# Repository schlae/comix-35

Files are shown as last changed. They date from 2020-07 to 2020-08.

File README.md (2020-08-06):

# COMIX-35 Home Computer
The COMIX-35 is an open-source clone of the 1980s COMX-35 8-bit home computer.
It uses the RCA 1802 microprocessor which is strange and slow but holds the
distinction of being the first CMOS microprocessor. The "35" is because the
original computer has 32K of main memory + 3K of video RAM.

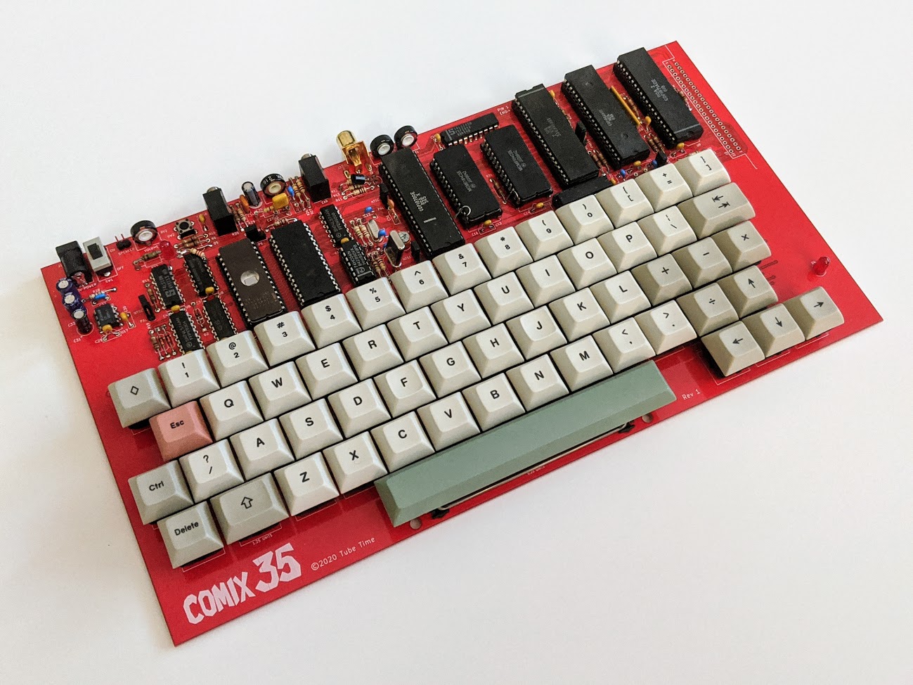
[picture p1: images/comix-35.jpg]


There are a number of differences between the COMIX-35 and the original:

* Single +5V power supply
* Uses SRAM; no stolen cycles for DRAM refresh
* Configurable PAL or NTSC by changing three jumpers and swapping a crystal
* Additional CPU crystal for a new turbo mode
* Mechanical key switches for your typing comfort
* Cassette input data light indicates incoming information

## Design files

Here are the design files. The BOM includes Mouser part numbers for everything
except the CDP1802, CDP1869, CDP1870, CDP1871, the trimmer capacitor (optional),
and the expansion slot header (also optional). I recommend you purchase IC
sockets for the four CDP parts, as well as for the ROM chip U15.

[Schematic](https://github.com/schlae/comix-35/blob/master/COMIX-35.pdf)

[Bill of Materials](https://github.com/schlae/comix-35/blob/master/COMIX-35.csv)

[Fab Files](https://github.com/schlae/comix-35/blob/master/fab/COMIX-35.zip)

The board is rather large, at 12 x 6.5 inches (304.8 x 165.1 mm), but it does
include the keyboard. It is a 2-layer design so it should be relatively cheap
to manufacture. A word of advice: pick out your keycap set first, then choose
the PCB color to match it.

The keyboard keyswitches are easily substituted for lower-cost ones from other
vendors. I recommend you purchase DSA-profile keycaps since some of the keys
are located in rows that are not typical. I ended up buying the [YMDK 125 DSA Dye Sub 9009 Retro PBT Full Keyset for MX](https://www.amazon.com/gp/product/B083L6FVPN/). You can choose whatever you want, but make sure there is a 1 unit
control key and a 1.25 unit shift key. The enter key needs to be 1.5 unit, so
I just used the tab key for that instead. If you have any doubt, check the PCB
layout which has the key cap unit sizes marked below each key.

I have not included part numbers for the 0.1" headers which usually come as a
long strip that you break into the appropriately-sized sections.

Most other components may be safely substituted. U4 is a little tricky. It
should be a 74HCU04 in order for the oscillators to operate, but in a pinch,
a 74HC04 will also work. A 74LS04 or a part from another logic family will
not work.

## Assembly notes
Since the standard COMX-35 ROM configures the CDP1869 to use extra-tall
characters, you need to tie CDP1869 pin 25 to CMA3. Do this by soldering a
jumper wire from pin 1-2 on JP6. If you wish to write your own code to deal
with short characters and more text pages, then install a 0.1" header and
jumper instead.

The default configuration for PAL is as follows:

| Location | PAL | NTSC |
| --- | --- | --- |
| JP1 | 2-3 | 1-2 |
| JP2 | 2-3 | 1-2 |
| JP3 | 2-3 | 1-2 |
| Y1 | 17.734 MHz | 14.318MHz |

The trimmer capacitor, C12, is optional. It allows you to adjust the color
image for best clarity. If you don't use it, then just stuff C13 with a 22pF
capacitor.

You can also configure your COMIX-35 for turbo mode which allows the CPU to
run at much higher frequencies than the original computer, limited only by
the maximum frequency of your particular CDP1802. Check the datasheet for the
variation you have, or experiment. Turbo mode is enabled by jumpering JP4 to
position 1-2. This enables the clock oscillator installed at Y3. To run at the
standard speed, set JP4 to 2-3.

If you use a 28C256 or 27C256 ROM, jumper JP5 will allow you to select between
the upper and lower 16K of ROM. This is useful if you want to use store two
different ROM binaries, such as the standard COMX-35 ROM and your own custom
program.

The COMX-35 ROM image is relatively easy to find so I will not provide it here.

## Video adjustments

There are two trimmer resistors that adjust the video:

* RV3 adjusts the sync pulse amplitude
* RV4 sets the overall video amplitude

The simplest way to get it working is to use an oscilloscope to set the sync
pulse amplitude to about 300mV and the video amplitude to about 700mV. If you
don't have an oscilloscope, set RV4 to the maximum, set RV3 to the minimum,
and then slowly increase RV3 until you get a stable picture. If the colors
are not saturated enough, you can decrease RV4.

The C12 trimmer capacitor, if you installed it, adjusts the frequency of the
colorburst by a small amount. Since the colorburst and the pixel clock are not
sychronized, you'll get a "shimmering" effect on colored pixels. Adjust C12
until you can't see shimmering anymore. 

## Loading programs off a computer using the cassette port
The process I've had success with is this:

* Run the [Emma 02 emulator](https://www.emma02.hobby-site.com/). Turn off SB
mode, turn off Turbo LOAD/SAVE. Make sure Auto LOAD/SAVE is turned on.
* Hit run. Press enter to go past the COMX screen and get to the BASIC prompt.
* Click the LOAD button and select the program you are interested in.
* From BASIC, type PSAVE.
* Name the file (it is actually a raw sound file, not WAV.)
* It will take a while but it will eventually save the cassette sound.
* Load the raw file in Audacity using File-\>Import-\>Raw Data. Select 22050 as
the sampling rate, mono, signed 16 bit little endian.
* You may wish to save the program as a regular WAV file at this point.
* Connect an audio cable between the COMIX-35's EAR jack and your computer's
speaker output.
* Make sure your computer has absolutely no audio processing going on at all.
No echo, no equalizer, nothing at all. You may have to really crank up the
volume.
* Hit play, and then adjust the input bias control until the data LED flickers.
* Stop, rewind, hit play, and then (on the COMIX-35) type "PLOAD" and hit
enter. If everything works, PLOAD will return you back to the BASIC prompt.
* Type RUN and hit enter to start the program.

The cassette interface is a bit tricky to work due to various reasons. The
input circuit uses a Schmitt-trigger buffer, so the DC bias of the incoming
audio signal must be adjusted to the halfway point of that threshold. This
is what the INPUT BIAS trimmer does.

You also need enough volume to be able to exceed the rising and falling
thresholds.

Tips and tricks if things don't work right the first time:
* Does your computer *really* provide clean audio? You've turned off all
effects processing? Audio managers, headphone bass boosters--all that *must* 
be turned off!
* Check your cables
* Check the volume level on the PC. If it is too low, it will not work
* Connect an oscilloscope to the cathode of D5 and make sure you see a clean
waveform

## Compatibility
Note that I have not tested the COMIX-35 with real COMX-35 accessories, such
as the expansion chassis, RAM boards, disk controllers, etc. It should work
with all these accessories except for the RAM expansion because it uses the RAS
and CAS lines. Since the COMIX-35 does not have the DRAM refresh circuit, these
signals don't exist on the expansion connector.

## License
This work is licensed under a Creative Commons Attribution-ShareAlike 4.0
International License. See [https://creativecommons.org/licenses/by-sa/4.0/](https://creativecommons.org/licenses/by-sa/4.0/).

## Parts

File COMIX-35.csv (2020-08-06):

Item | Qty | Reference(s) | Value | Digikey | Mouser
1 | 20 | C1, C2, C3, C4, C5, C7, C8, C9, C10, C11, C14, C16, C17, C20, C21, C22, C25, C26, C29, C30 | 0.1uF |  | 581-SA105E104M
2 | 1 | C6 | 100uF |  | 667-ECA-1CM101I
3 | 1 | C12 | CHROMA | 2447-GKG30015-ND
4 | 6 | C13, C15, C18, C19, C23, C24 | 22pF |  | 810-FG28C0G2A220JNT0
5 | 1 | C27 | 1uF |  | 810-FG24X7R1H334KNT6
6 | 1 | C28 | 1000pF |  | 810-FG28X7R1H102KNT6
7 | 2 | C31, C35 | 10uF |  | 667-ECA-1CM100I
8 | 1 | C32 | 0.047uF |  | 810-FA28X7R1H47300
9 | 1 | C33 | 220uF |  | 647-UVY1E221MED1TD
10 | 1 | C34 | 0.33uF |  | 810-FG28X7R1H334KRT0
11 | 1 | C36 | 120pF |  | 810-FG28C0G1H121JNT6
12 | 4 | D1, D2, D3, D5 | 1N4148 |  | 512-1N4148
13 | 1 | D4 | POWER |  | 859-LTL-4213
14 | 1 | D6 | DATA |  | 859-LTL-4213
15 | 1 | J1 | Barrel_Jack_Switch |  | 490-PJ-002B
16 | 1 | J2 | EXPANSION | S3316-ND
17 | 1 | J3 | VIDEO |  | 161-0360-E
18 | 1 | J4 | EAR |  | 490-SJ1-3533NG
19 | 1 | J5 | Conn_01x02
20 | 1 | J6 | MIC |  | 490-SJ1-3533NG
21 | 3 | JP1, JP2, JP3 | NTSC/PAL
22 | 1 | JP4 | CLKSEL
23 | 1 | JP5 | BANK
24 | 1 | JP6 | PAGE
25 | 1 | M1 | Stiffener |  | 540-0G990743
26 | 1 | Q1 | 2N3904 |  | 512-2N3904BU
27 | 15 | R1, R3, R6, R14, R15, R16, R18, R19, R20, R21, R22, R26, R27, R31, R32 | 10K |  | 603-CFR-25JB-52-10K
28 | 1 | R2 | 100K |  | 603-CFR-25JB-52-100K
29 | 3 | R4, R9, R23 | 1M |  | 603-CFR-25JR-521M
30 | 4 | R5, R10, R25, R29 | 1K |  | 603-CFR-25JR-521K
31 | 3 | R7, R12, R33 | 220 |  | 603-CFR-25JR-52220R
32 | 2 | R11, R28 | 10 |  | 603-CFR-25JR-5210R
33 | 1 | R13 | 75 |  | 603-CFR-25JR-5275R
34 | 1 | R17 | 10M |  | 603-CFR-25JT-52-10M
35 | 1 | R24 | DNI |  | DNI
36 | 1 | R30 | 100 |  | 603-CFR-25JR-52100R
37 | 1 | RN1 | 10K x 8 |  | 652-4609X-1LF-10K
38 | 1 | RV1 | 47K |  | 531-PT10LH01473A22S
39 | 3 | RV2, RV3, RV4 | 10K |  | 531-PT10H-10K-S
40 | 1 | SW1 | POWER |  | 633-CS12ANW03
41 | 1 | SW2 | RESET |  | 612-TL1105B
42 | 58 | SW3-SW60 |  |  | 540-MX1A-11NW
43 | 1 | U1 | CDP1802ACE
44 | 1 | U2 | 74HC574 |  | 595-SN74HC574N
45 | 2 | U3, U5 | 74HC74 |  | 595-SN74HC74N
46 | 1 | U4 | 74HCU04 |  | 595-SN74HCU04N
47 | 1 | U6 | 74HC10 |  | 595-SN74HC10N
48 | 1 | U7 | 74HC86 |  | 595-SN74HC86N
49 | 1 | U8 | 74HC14 |  | 595-SN74HC14N
50 | 1 | U9 | CDP1871
51 | 1 | U10 | CDP1869
52 | 1 | U11 | 74HC245 |  | 595-SN74HC245N
53 | 3 | U12, U13, U16 | AS6C62256 |  | 913-AS6C62256-55PCN
54 | 1 | U14 | CDP1870
55 | 1 | U15 | 28C256 |  | 556-AT28C25615PU
56 | 1 | U17 | LM386 |  | 926-LM386N-4/NOPB
57 | 1 | Y1 | 14.318MHz |  | 815-ABL-14.31818B2
58 | 1 | Y2 | 11.2896MHz |  | 815-ABL-11.2896-B4Y
59 | 1 | Y3 | DNI |  | DNI

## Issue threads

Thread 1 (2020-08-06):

Crystal oscillator circuit and U4

Ian-May, 2020-08-06:
You are correct that a specific component is needed for U4, but a 74HC04 is not what is required for the circuit you have chosen. Your oscillator circuit is for use with unbuffered inverters (like a 74HCU04) which typically have a voltage gain in the hundreds. A buffered inverter (like a 74HC04) has a voltage gain of over 10,000. See National Semiconductor application note AN-340 which is on pdf page 76 of this data book http://bitsavers.org/components/national/_dataBooks/1983_National_74HC_Databook.pdf . A crystal-controlled oscillator should not oscillate without a crystal. If you remove the crystal from your 74HC04 oscillator it will, in my experience, oscillate at around 40 MHz or higher. With the crystal in circuit, it may oscillate at the crystal frequency, or the frequency measured without the crystal, or both at the same time. With a 74HCU04 in use it will not oscillate without a crystal. The disadvantage of the 74HCU04 is higher power supply current, which is unlikely to be an issue in your design. Using the other inverters in the 74HCU04 as inverters isn't a problem, it is a few nS faster than a 74HC04. See 74HC data book pdf page 130 for the 74HCU04 data sheet, oscillator circuit page 132. Otherwise nice re-design, not using 4000 CMOS is a good idea and your keyboard is light years ahead of the original.

schlae, 2020-08-06:
Ha, I knew someone would comment on that. I did a bunch of experiments with different inverters (even got it working with 74LS04 but with wildly different component values). You are correct, ideally it should be a 74HCU04. I've found that, with the resistor values in the BOM, it works fine with a 74HC04 and does not oscillate without a crystal in the circuit. The measured gain of the 'HC04 wasn't quite as high as you've quoted, but I'm sure it varies quite a bit part to part. The important part is that other folks should be able to get away with using an HC04 if they're not able to source the HCU04.

Regardless, I've updated the design and added some further comments to the readme to clarify this.

Ian-May, 2020-08-08:
Glad to have fulfilled your expectations :) Thanks for making the changes. The gain figures came from the app. note, which is nearly 40 years old, so little wonder parts are different today. Can I ask a couple of questions? Who made your PCB (I may be able to avoid tooling charges if I use the same manufacturer) and what did it cost? Thanks.

Closed 2020-08-06.

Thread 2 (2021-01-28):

BOM error?

frax, 2021-01-28:
C27 is 1uF in the BOM and the schmatics but links to 810-FG24X7R1H334KNT6 which is 0.33uF.

prpplague, 2021-03-19:
any update on this?

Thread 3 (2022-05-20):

3D printed Case

akoutsou77, 2022-05-20:
Although it is a WIP I think it looks promising. I will upload the files once finished

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

akoutsou77, 2022-06-22:
Here you may find the STL files for the case and a number of images of my "makes" :-)

https://www.thingiverse.com/thing:5405097

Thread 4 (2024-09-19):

Key auto-repeats under PAL setting

0ddjob, 2024-09-19:
Hi,

My machine is configured as PAL with Y1 = 17.73MHz and JP1/2/3 = PAL.

However the JP3 = PAL setting causes keys to auto-repeat with BASIC v1.03 and v1.04 (haven't tried others).

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

When it is set to NTSC then the auto-repeat issue is solved, but the screen display is incorrect (top line is repeated at bottom).

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

The diodes are installed as per the PCB silkscreen: D1 cathode north (PAL) and D2 cathode south (NTSC).

I can see that JP3 affects the RPT/RTP auto-repeat signal from the CDP1871 and the EF2 signal into the CDP1802 but I don't really understand why NTSC or PAL makes a difference.

Thanks!

Brett.

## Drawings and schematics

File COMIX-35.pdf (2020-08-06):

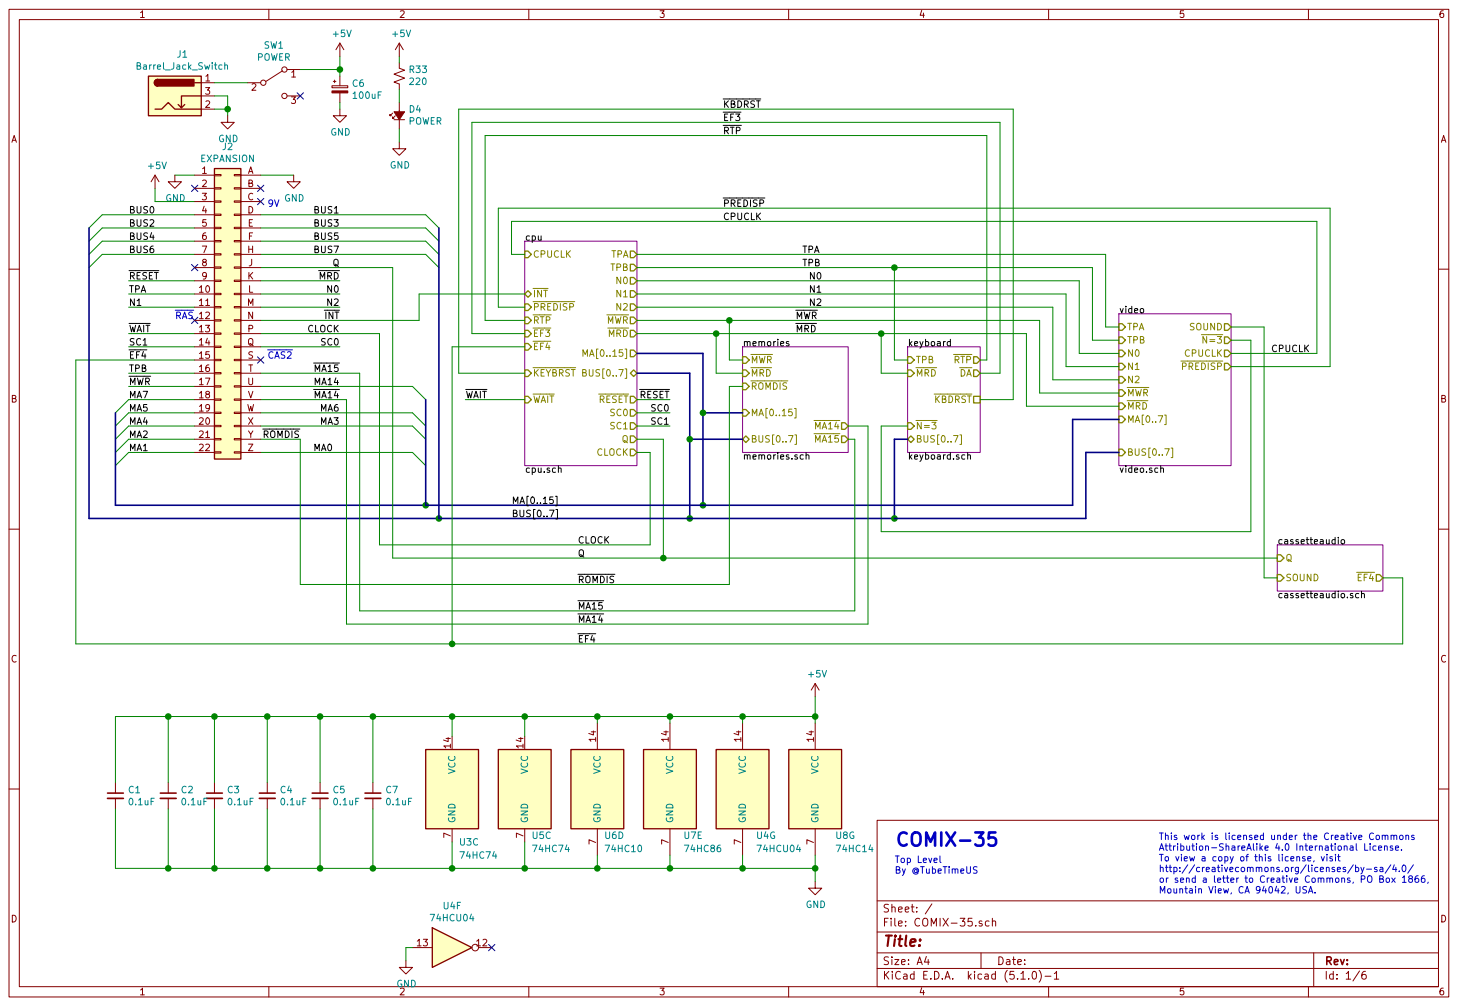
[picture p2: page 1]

Id: 1/6 Title: File: COMIX-35.sch Sheet: / VCC 14 GND

http://creativecommons.org/licenses/by-sa/4.0/ or send a letter to Creative Commons, PO Box 1866, Mountain View, CA 94042, USA. COMIX-35

This work is licensed under the Creative Commons Attribution-ShareAlike 4.0 International License. To view a copy of this license, visit

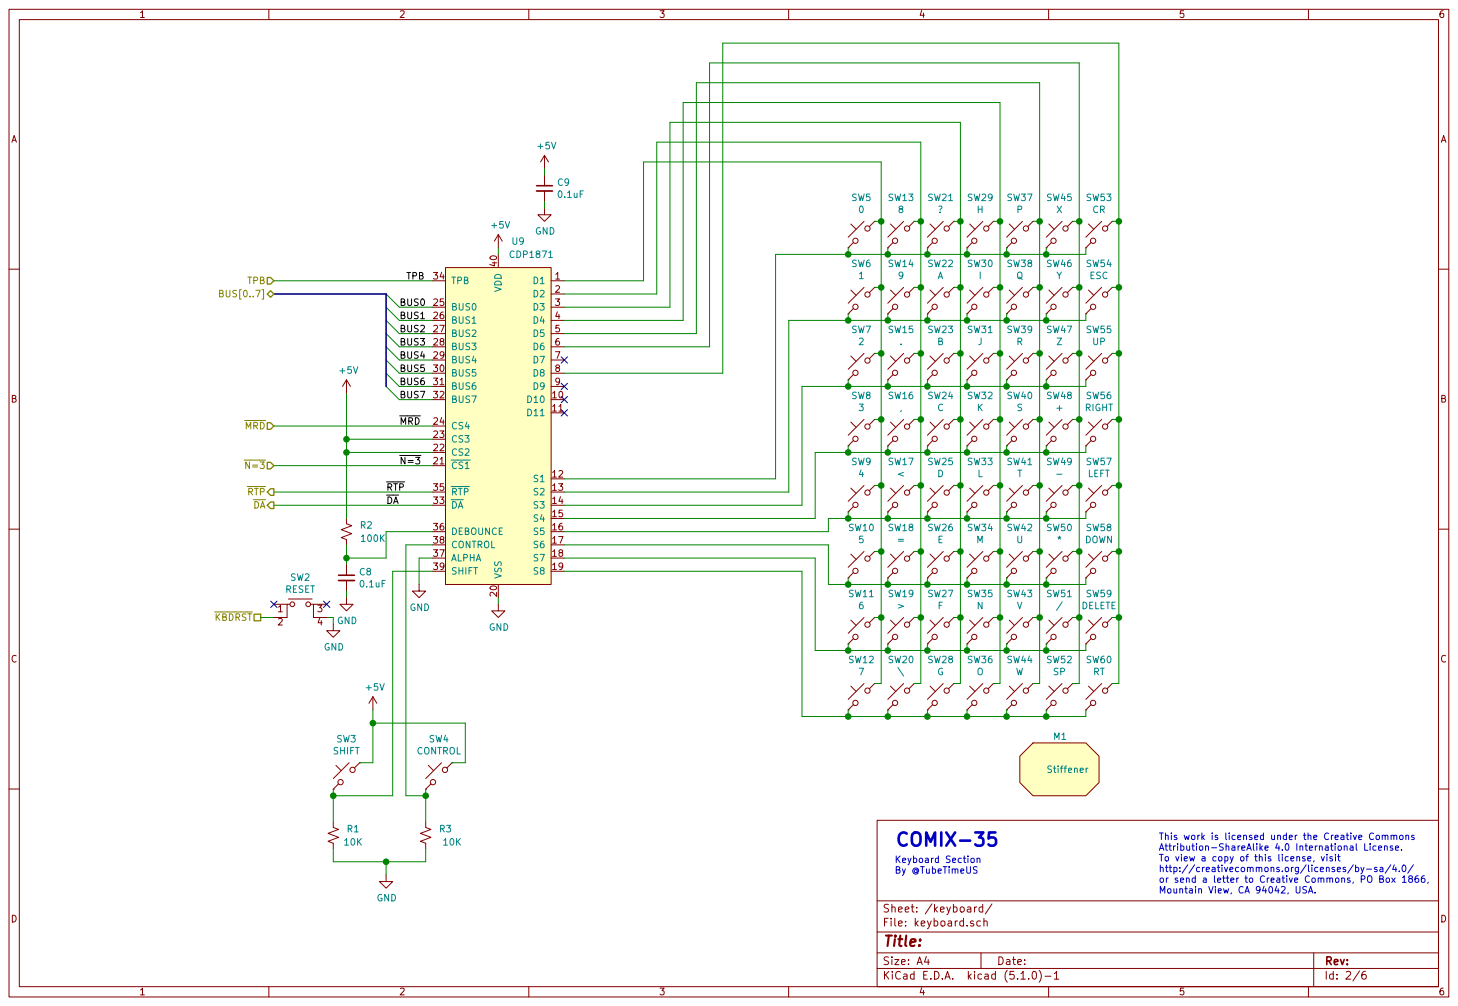
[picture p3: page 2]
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

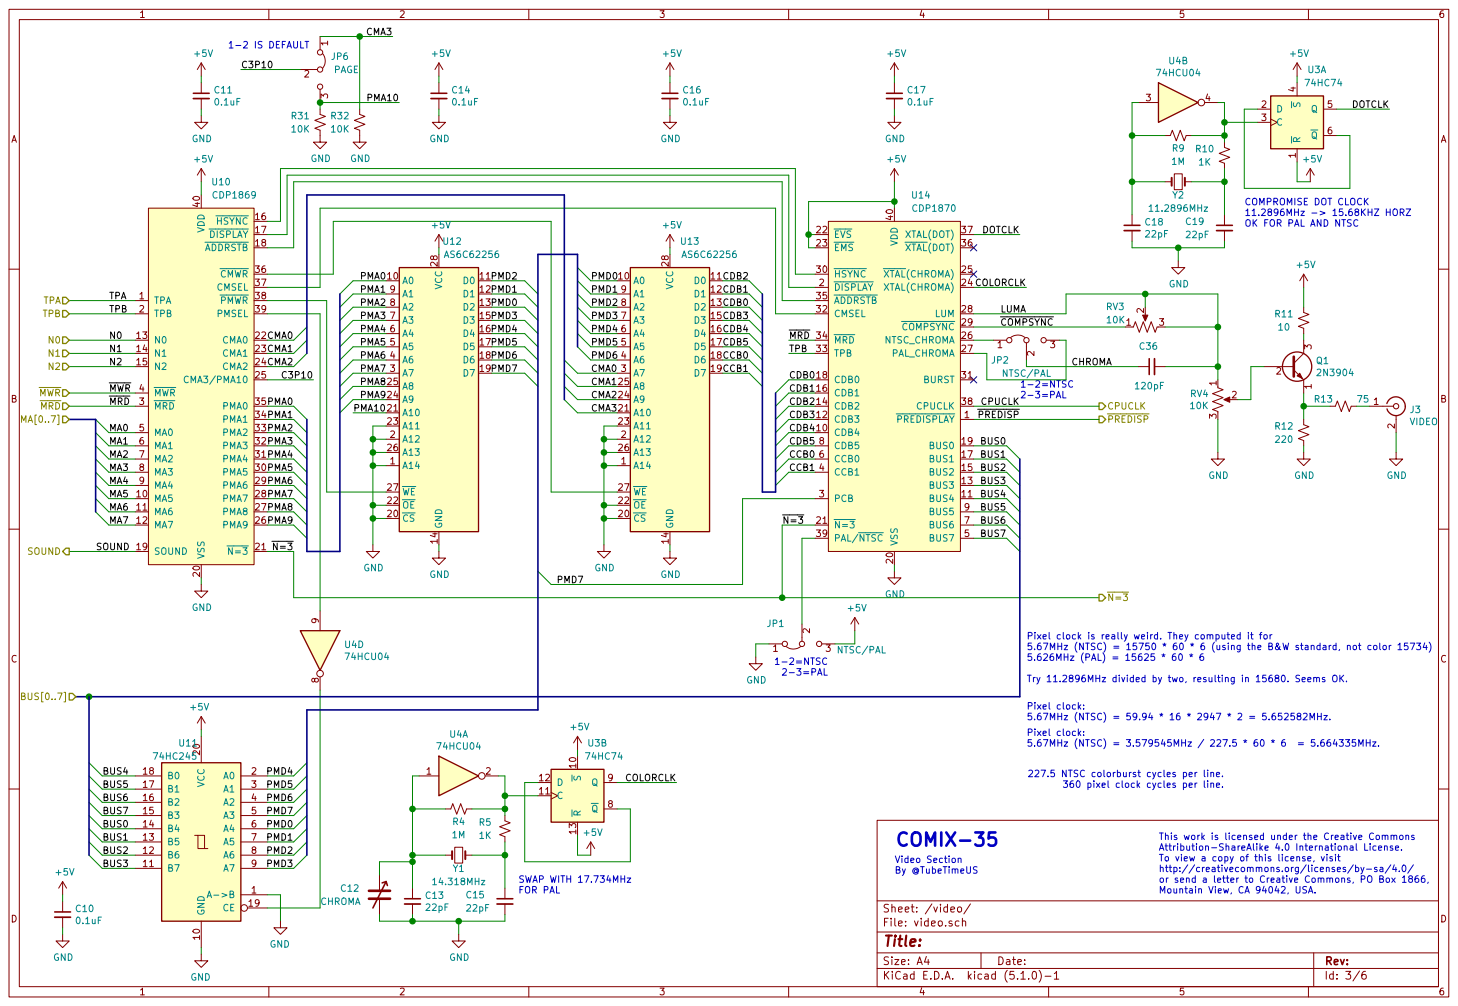
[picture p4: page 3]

11.2896MHz -> 15.68KHZ HORZ OK FOR PAL AND NTSC

Pixel clock is really weird. They computed it for
5.67MHz (NTSC) = 15750 * 60 * 6 (using the B&W standard, not color 15734)
5.626MHz (PAL) = 15625 * 60 * 6

Try 11.2896MHz divided by two, resulting in 15680. Seems OK. Pixel clock: 5.67MHz (NTSC) = 59.94 * 16 * 2947 * 2 = 5.652582MHz. Pixel clock: 5.67MHz (NTSC) = 3.579545MHz / 227.5 * 60 * 6 = 5.664335MHz.

227.5 NTSC colorburst cycles per line.

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

Video Section By @TubeTimeUS

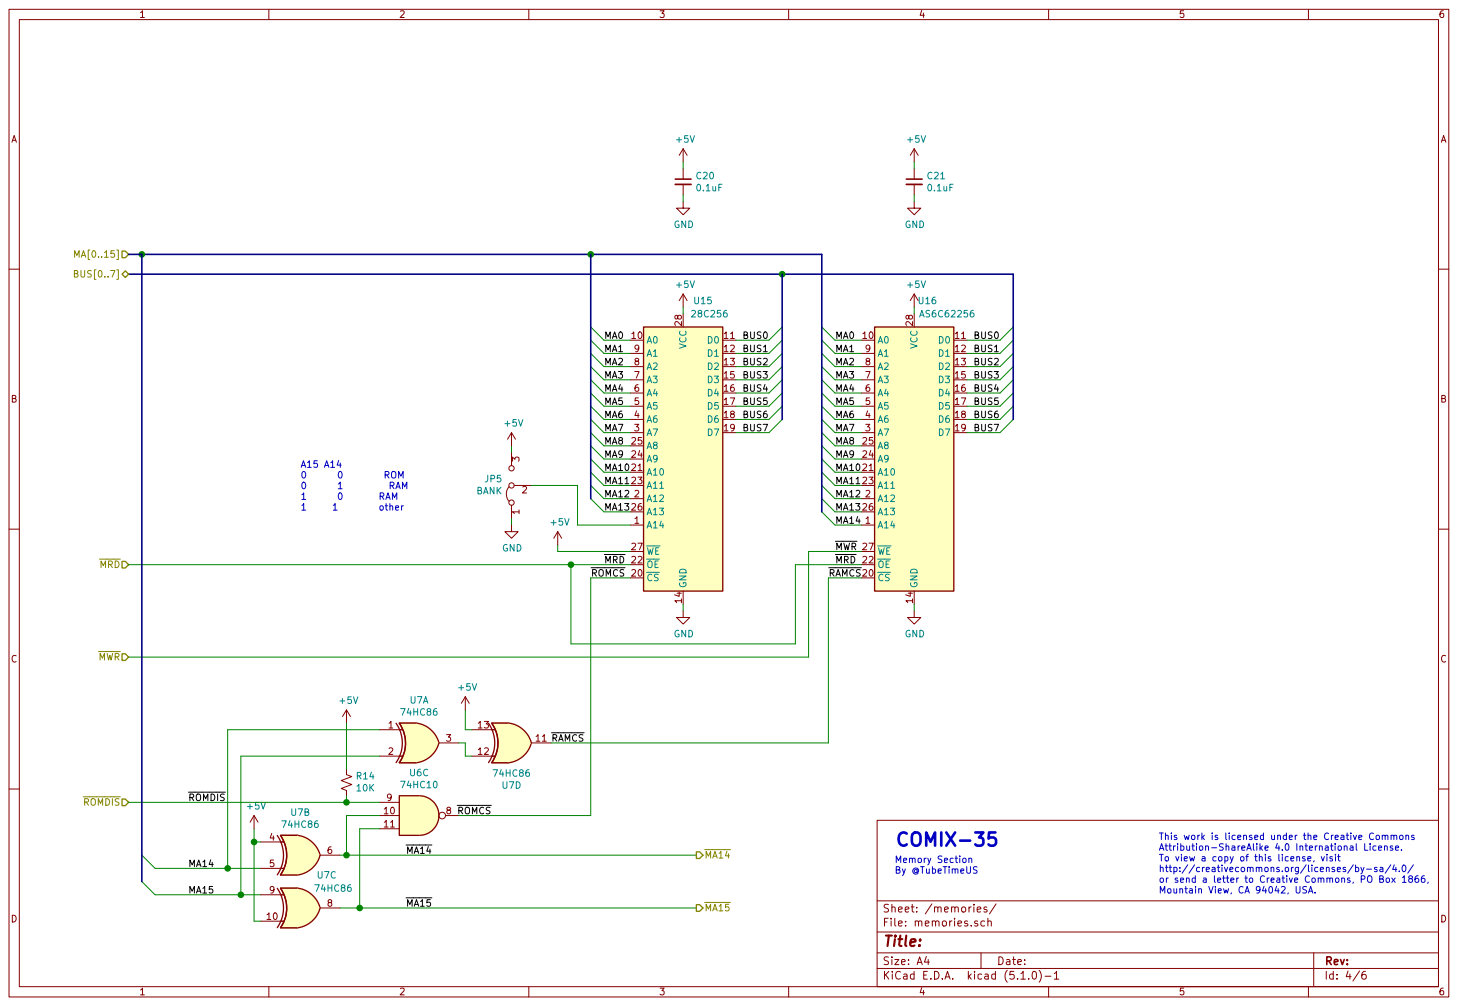
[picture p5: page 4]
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

Id: 4/6 Title: File: memories.sch Sheet: /memories/

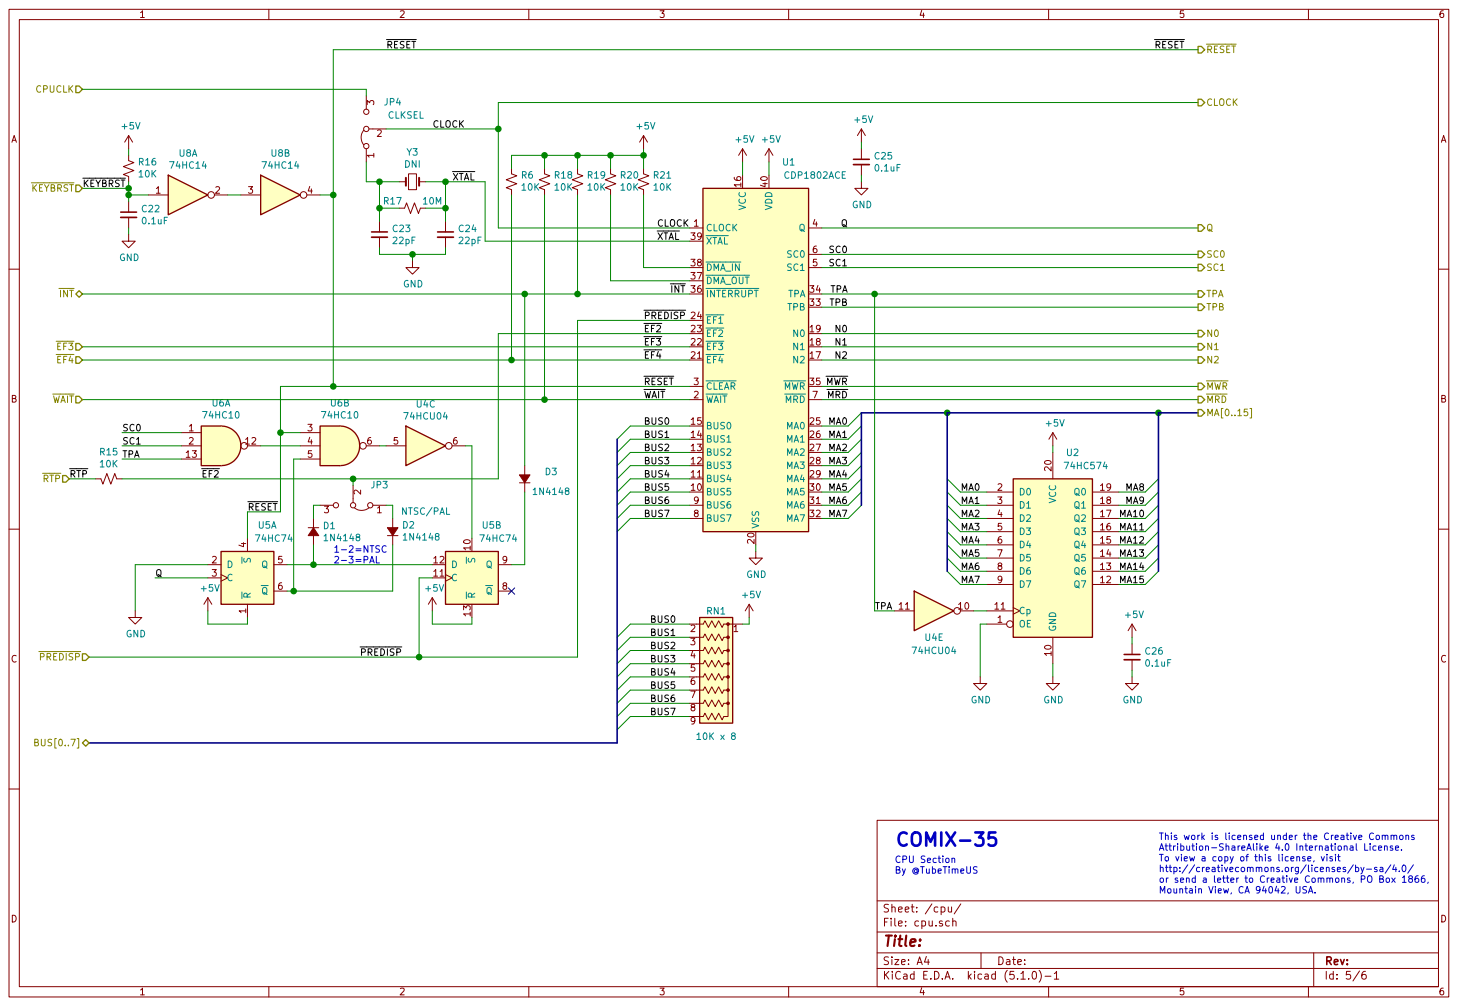
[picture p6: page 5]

TPA
TPB N0 N1 N2 MWR MRD MA[0..15]

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

CPU Section By @TubeTimeUS

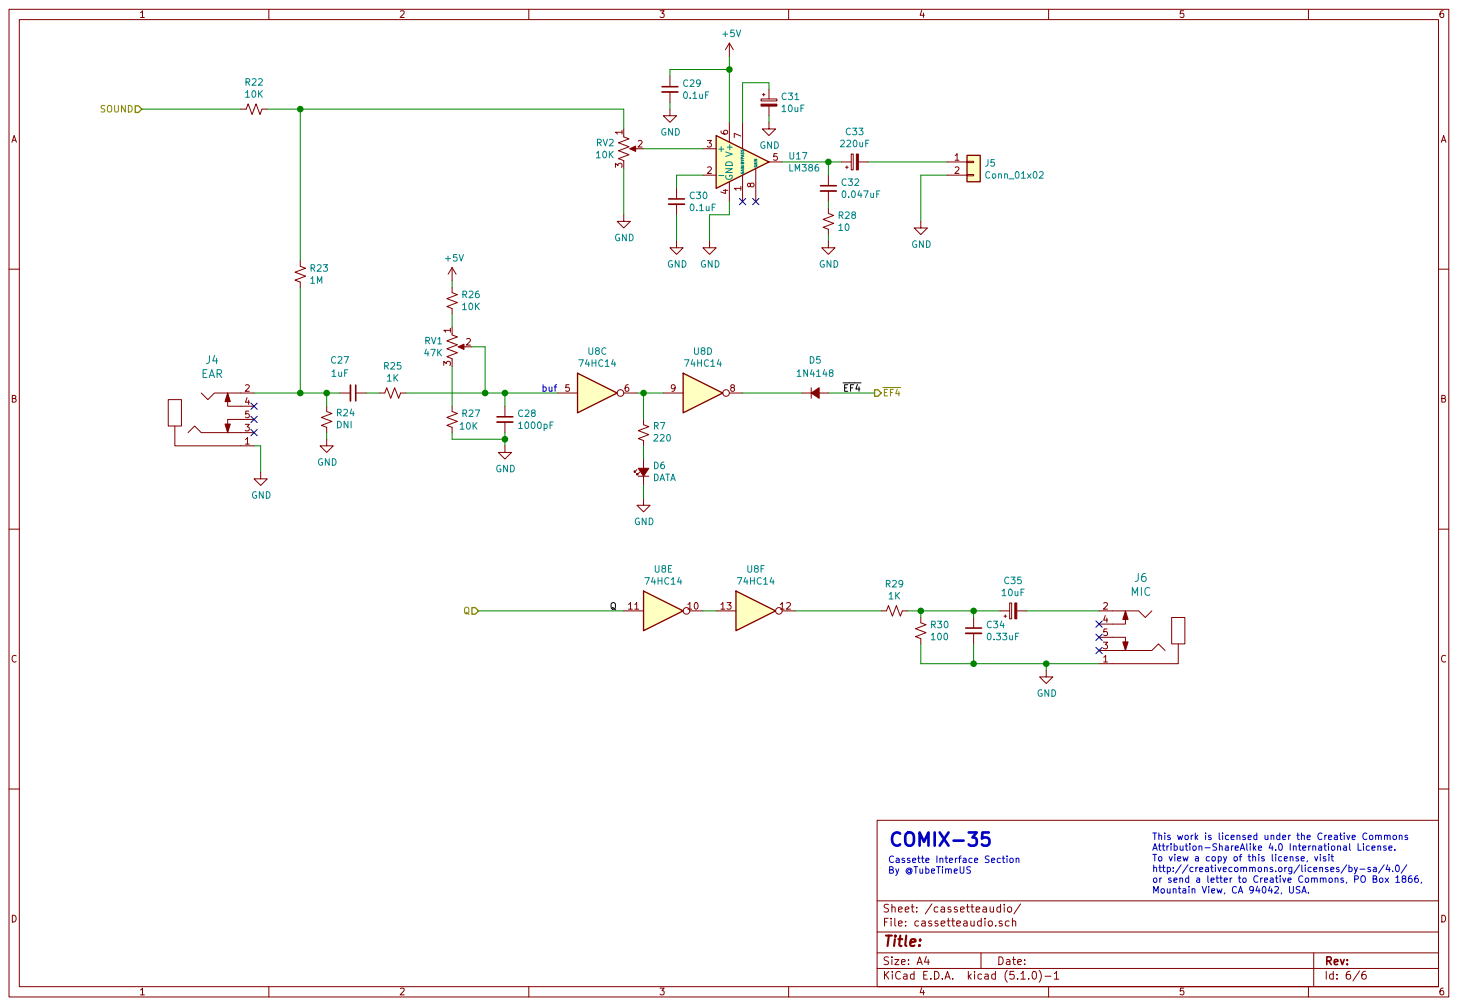
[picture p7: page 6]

Id: 6/6 Title: File: cassetteaudio.sch Sheet: /cassetteaudio/ R29

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

Cassette Interface Section By @TubeTimeUS

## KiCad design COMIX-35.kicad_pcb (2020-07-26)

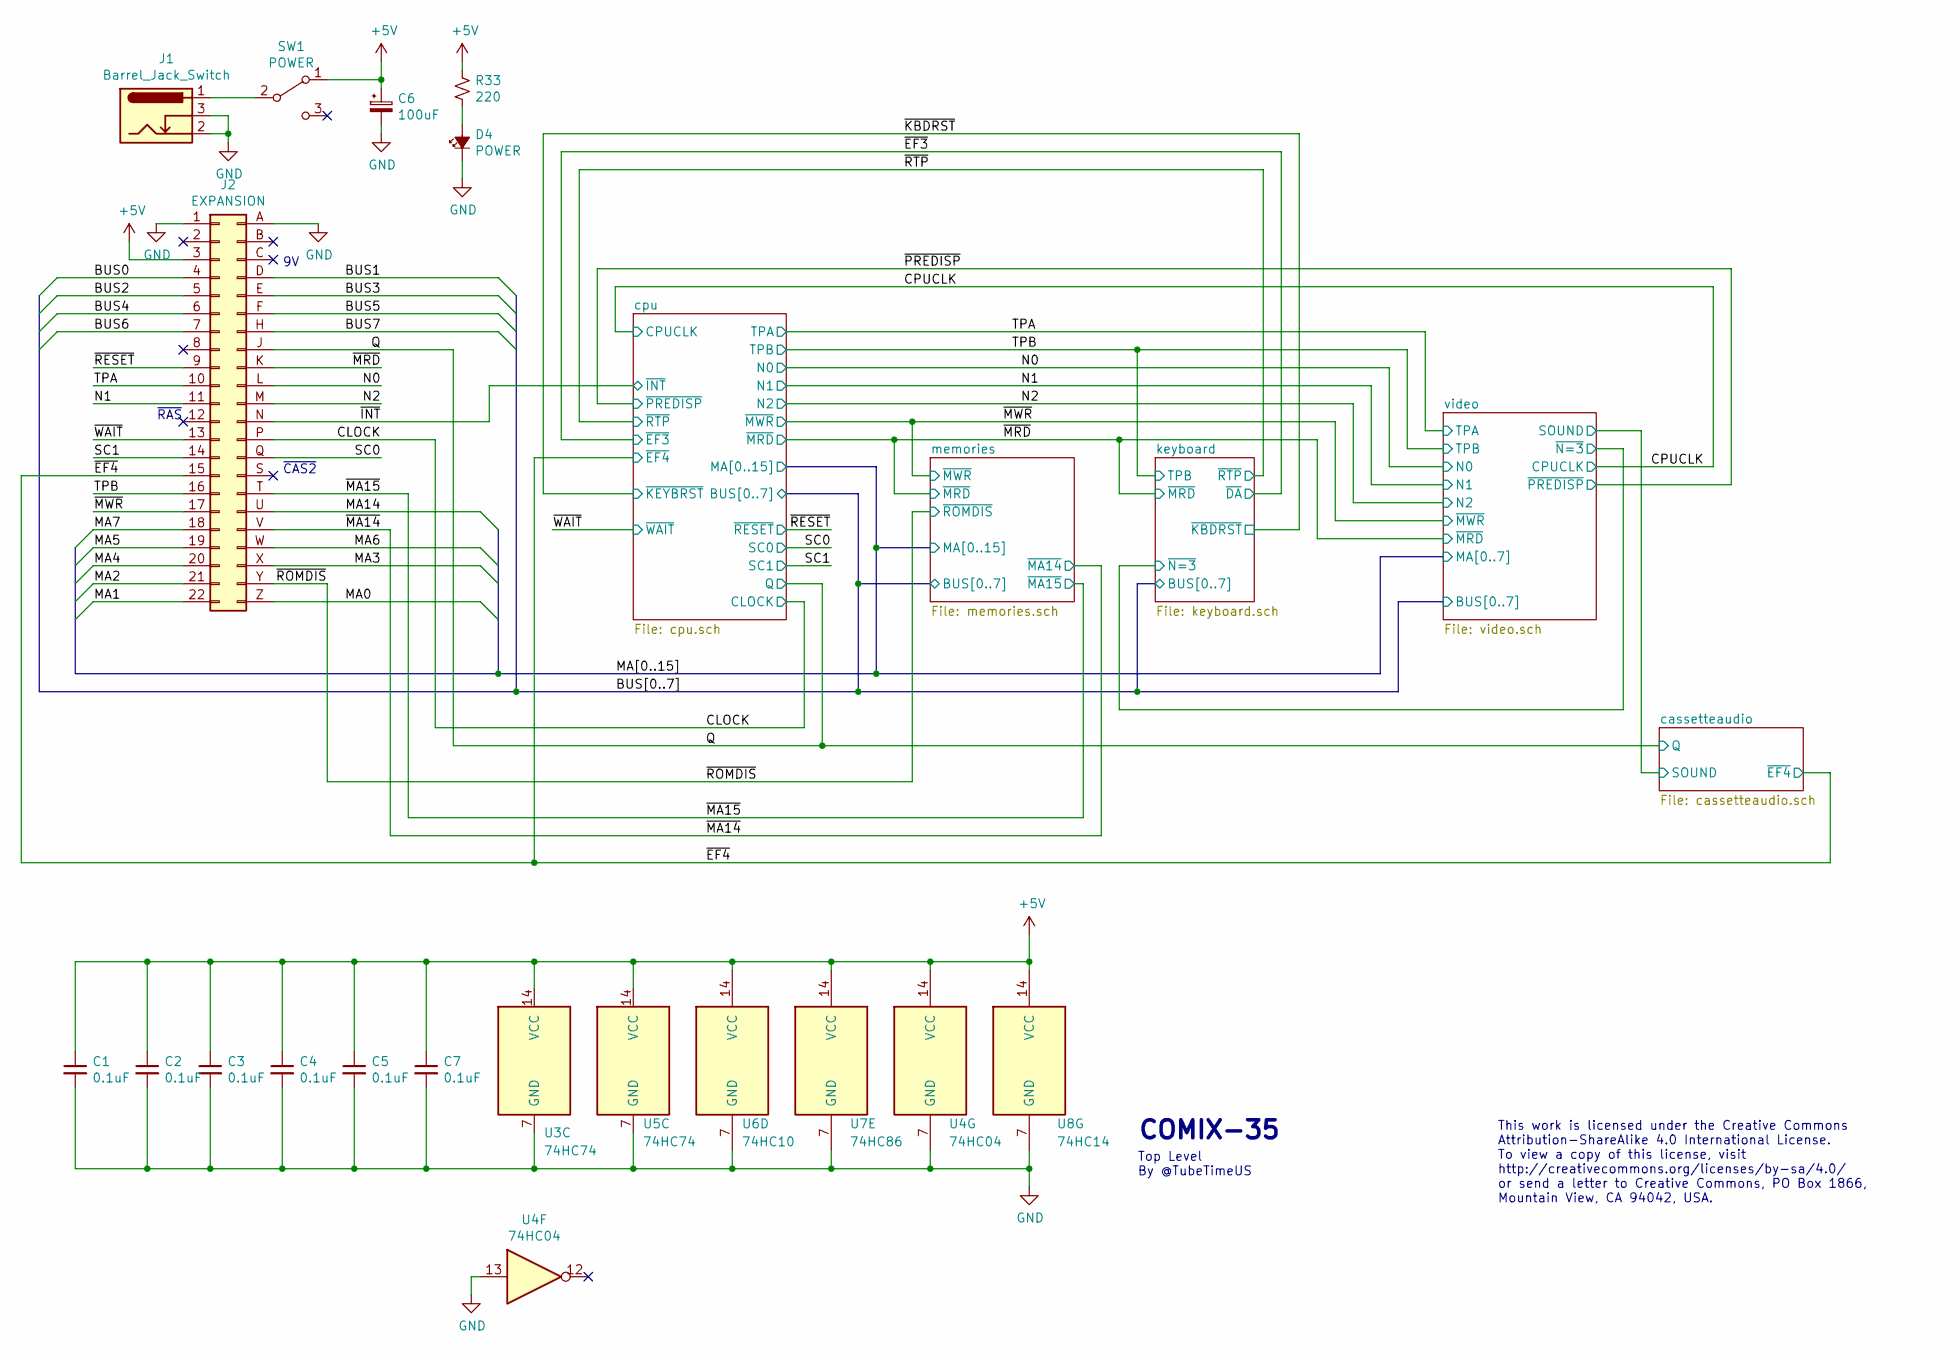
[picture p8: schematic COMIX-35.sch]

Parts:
C1, C2, C3, C4, C5, C7: 0.1uF; CAPAC200; Mouser 581-SA105E104M
C6: 100uF; CAPAE200P500X1100; Mouser 667-ECA-1CM101I
D4: POWER; LED_D5.0mm; Mouser 859-LTL-4213
J1: Barrel_Jack_Switch; CUI_PJ-002B; Mouser 490-PJ-002B
J2: EXPANSION; SULLINS_EBC22DRAS_ALT; Digikey S3316-ND
R33: 220; RESA500; Mouser 603-CFR-25JR-52220R
SW1: POWER; NKK_CS12ANW03; Mouser 633-CS12ANW03
U3, U5: 74HC74; DIP254P762X635-14; Mouser 595-SN74HC74N
U4: 74HC04; DIP254P762X635-14; Mouser 595-SN74HC04N
U6: 74HC10; DIP254P762X635-14; Mouser 595-SN74HC10N
U7: 74HC86; DIP254P762X635-14; Mouser 595-SN74HC86N
U8: 74HC14; DIP254P762X635-14; Mouser 595-SN74HC14N

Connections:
+5V: C1.1, C2.1, C3.1, C4.1, C5.1, C6.1, C7.1, J2.3, R33.2, SW1.1 (A), U3.14 (VCC), U4.14 (VCC), U5.14 (VCC), U6.14 (VCC), U7.14 (VCC), U8.14 (VCC); also elsewhere on the board
/BUS0: J2.4; also elsewhere on the board
/BUS1: J2.D; also elsewhere on the board
/BUS2: J2.5; also elsewhere on the board
/BUS3: J2.E; also elsewhere on the board
/BUS4: J2.6; also elsewhere on the board
/BUS5: J2.F; also elsewhere on the board
/BUS6: J2.7; also elsewhere on the board
/BUS7: J2.H; also elsewhere on the board
/CLOCK: J2.P; also elsewhere on the board
/MA0: J2.Z; also elsewhere on the board
/MA1: J2.22; also elsewhere on the board
/MA2: J2.21; also elsewhere on the board
/MA3: J2.X; also elsewhere on the board
/MA4: J2.20; also elsewhere on the board
/MA5: J2.19; also elsewhere on the board
/MA6: J2.W; also elsewhere on the board
/MA7: J2.18; also elsewhere on the board
/MA14: J2.U; also elsewhere on the board
/N0: J2.L; also elsewhere on the board
/N1: J2.11; also elsewhere on the board
/N2: J2.M; also elsewhere on the board
/Q: J2.J; also elsewhere on the board
/SC0: J2.Q; also elsewhere on the board
/SC1: J2.14; also elsewhere on the board
/TPA: J2.10; also elsewhere on the board
/TPB: J2.16; also elsewhere on the board
/~EF4: J2.15; also elsewhere on the board
/~INT: J2.N; also elsewhere on the board
/~MA14: J2.V; also elsewhere on the board
/~MA15: J2.T; also elsewhere on the board
/~MRD: J2.K; also elsewhere on the board
/~MWR: J2.17; also elsewhere on the board
/~RESET: J2.9; also elsewhere on the board
/~ROMDIS: J2.Y; also elsewhere on the board
/~WAIT: J2.13; also elsewhere on the board
GND: C1.2, C2.2, C3.2, C4.2, C5.2, C6.2, C7.2, D4.1 (K), J1.2, J1.3, J2.1, J2.A, U3.7 (GND), U4.7 (GND), U4.13, U5.7 (GND), U6.7 (GND), U7.7 (GND), U8.7 (GND); also elsewhere on the board
unnamed: D4.2 (A), R33.1
unnamed: J1.1, SW1.2 (B)

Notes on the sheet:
~RAS
~CAS2
This work is licensed under the Creative Commons Attribution-ShareAlike 4.0 International License. To view a copy of this license, visit http://creativecommons.org/licenses/by-sa/4.0/ or send a letter to Creative Commons, PO Box 1866, Mountain View, CA 94042, USA.
COMIX-35
Top Level By @TubeTimeUS

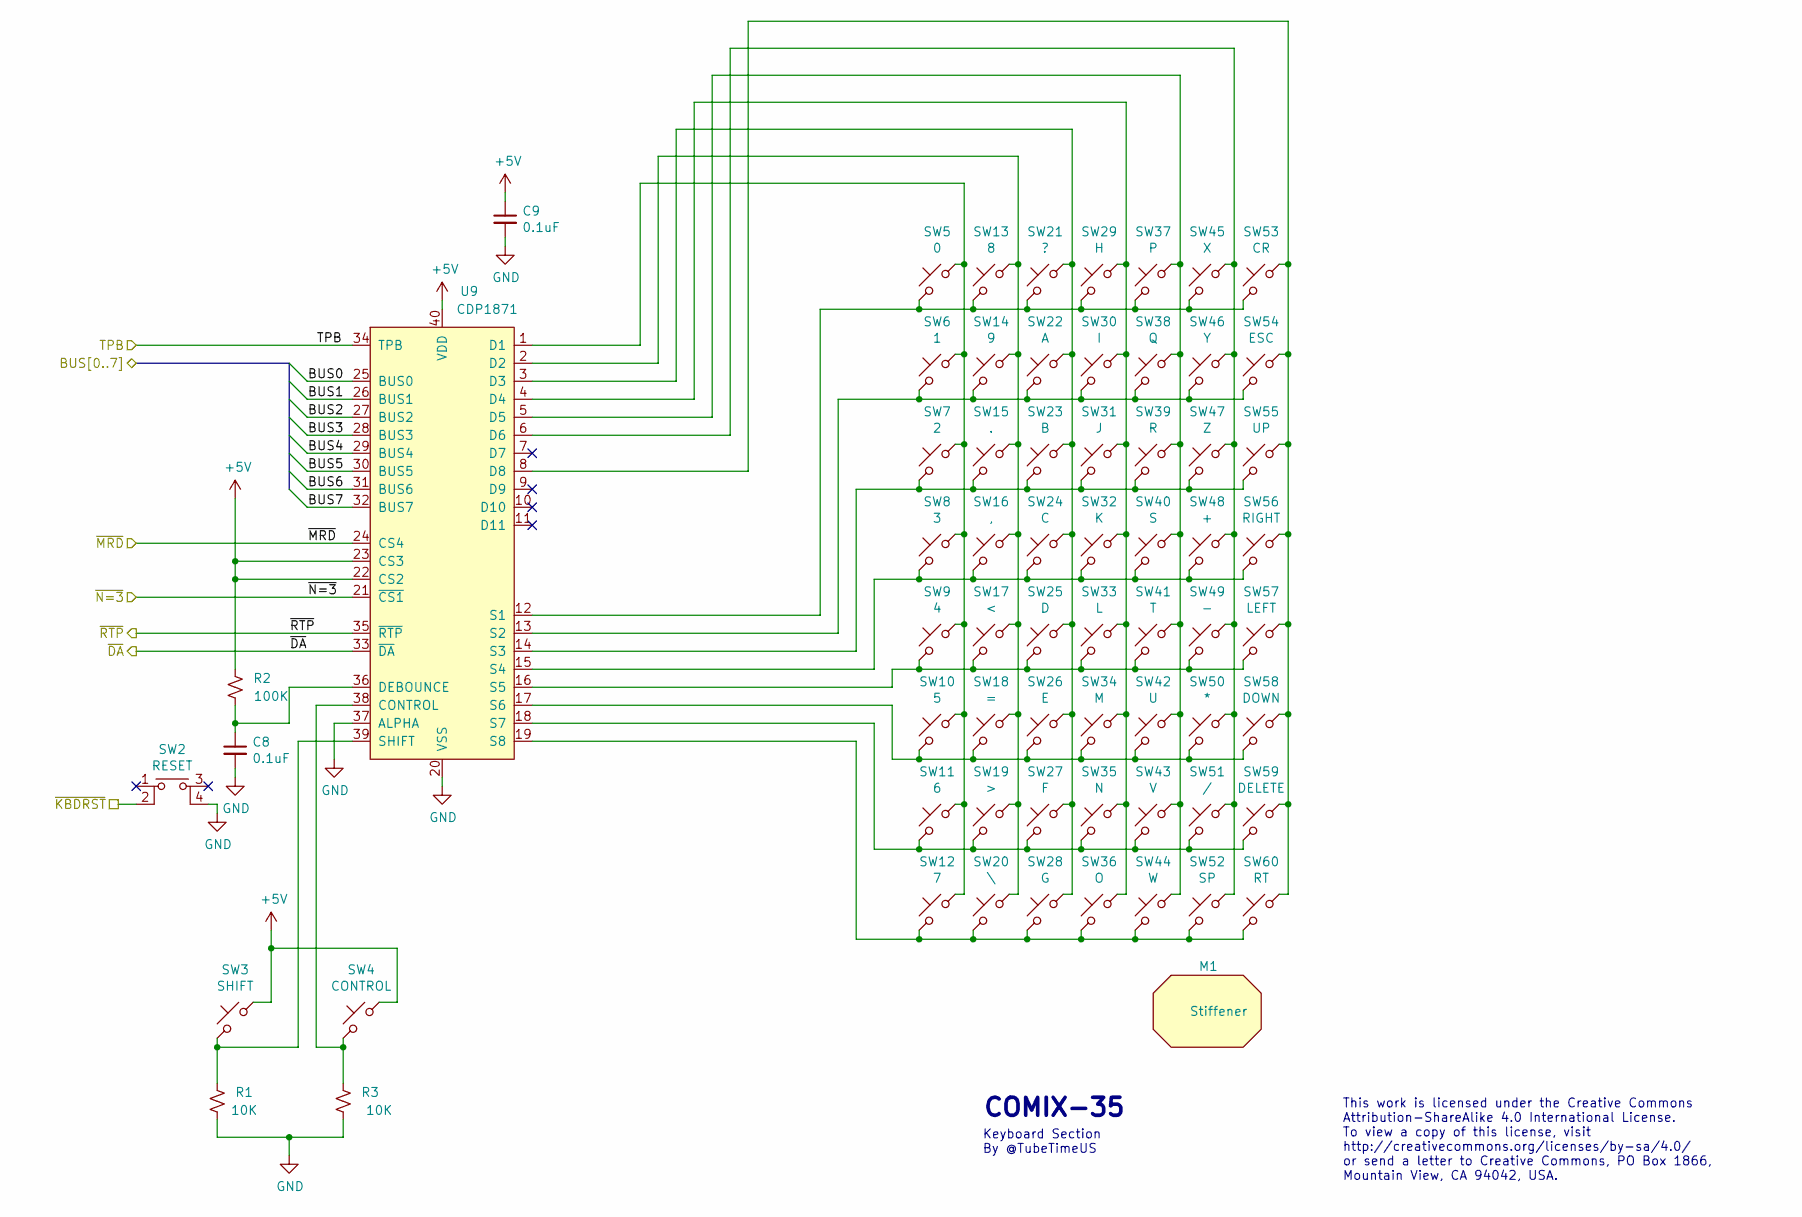
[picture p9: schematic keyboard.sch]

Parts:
C8, C9: 0.1uF; CAPAC200; Mouser 581-SA105E104M
M1: Stiffener; CHERRY_ST2; Mouser 540-0G990743
R1, R3: 10K; RESA500; Mouser 603-CFR-25JB-52-10K
R2: 100K; RESA500; Mouser 603-CFR-25JB-52-100K
SW2: RESET; ESWITCH_TL1105; Mouser 612-TL1105B
SW3: SHIFT; CHERRY_MX_125; Mouser 540-MX1A-11NW
SW4: CONTROL; CHERRY_MX; Mouser 540-MX1A-11NW
SW5: 0; CHERRY_MX; Mouser 540-MX1A-11NW
SW6: 1; CHERRY_MX; Mouser 540-MX1A-11NW
SW7: 2; CHERRY_MX; Mouser 540-MX1A-11NW
SW8: 3; CHERRY_MX; Mouser 540-MX1A-11NW
SW9: 4; CHERRY_MX; Mouser 540-MX1A-11NW
SW10: 5; CHERRY_MX; Mouser 540-MX1A-11NW
SW11: 6; CHERRY_MX; Mouser 540-MX1A-11NW
SW12: 7; CHERRY_MX; Mouser 540-MX1A-11NW
SW13: 8; CHERRY_MX; Mouser 540-MX1A-11NW
SW14: 9; CHERRY_MX; Mouser 540-MX1A-11NW
SW15: .; CHERRY_MX; Mouser 540-MX1A-11NW
SW16: ,; CHERRY_MX; Mouser 540-MX1A-11NW
SW17: <; CHERRY_MX; Mouser 540-MX1A-11NW
SW18: =; CHERRY_MX; Mouser 540-MX1A-11NW
SW19: >; CHERRY_MX; Mouser 540-MX1A-11NW
SW20: \\; CHERRY_MX; Mouser 540-MX1A-11NW
SW21: ?; CHERRY_MX; Mouser 540-MX1A-11NW
SW22: A; CHERRY_MX; Mouser 540-MX1A-11NW
SW23: B; CHERRY_MX; Mouser 540-MX1A-11NW
SW24: C; CHERRY_MX; Mouser 540-MX1A-11NW
SW25: D; CHERRY_MX; Mouser 540-MX1A-11NW
SW26: E; CHERRY_MX; Mouser 540-MX1A-11NW
SW27: F; CHERRY_MX; Mouser 540-MX1A-11NW
SW28: G; CHERRY_MX; Mouser 540-MX1A-11NW
SW29: H; CHERRY_MX; Mouser 540-MX1A-11NW
SW30: I; CHERRY_MX; Mouser 540-MX1A-11NW
SW31: J; CHERRY_MX; Mouser 540-MX1A-11NW
SW32: K; CHERRY_MX; Mouser 540-MX1A-11NW
SW33: L; CHERRY_MX; Mouser 540-MX1A-11NW
SW34: M; CHERRY_MX; Mouser 540-MX1A-11NW
SW35: N; CHERRY_MX; Mouser 540-MX1A-11NW
SW36: O; CHERRY_MX; Mouser 540-MX1A-11NW
SW37: P; CHERRY_MX; Mouser 540-MX1A-11NW
SW38: Q; CHERRY_MX; Mouser 540-MX1A-11NW
SW39: R; CHERRY_MX; Mouser 540-MX1A-11NW
SW40: S; CHERRY_MX; Mouser 540-MX1A-11NW
SW41: T; CHERRY_MX; Mouser 540-MX1A-11NW
SW42: U; CHERRY_MX; Mouser 540-MX1A-11NW
SW43: V; CHERRY_MX; Mouser 540-MX1A-11NW
SW44: W; CHERRY_MX; Mouser 540-MX1A-11NW
SW45: X; CHERRY_MX; Mouser 540-MX1A-11NW
SW46: Y; CHERRY_MX; Mouser 540-MX1A-11NW
SW47: Z; CHERRY_MX; Mouser 540-MX1A-11NW
SW48: +; CHERRY_MX; Mouser 540-MX1A-11NW
SW49: -; CHERRY_MX; Mouser 540-MX1A-11NW
SW50: *; CHERRY_MX; Mouser 540-MX1A-11NW
SW51: /; CHERRY_MX; Mouser 540-MX1A-11NW
SW52: SP; CHERRY_MX_625; Mouser 540-MX1A-11NW
SW53: CR; CHERRY_MX_150; Mouser 540-MX1A-11NW
SW54: ESC; CHERRY_MX; Mouser 540-MX1A-11NW
SW55: UP; CHERRY_MX; Mouser 540-MX1A-11NW
SW56: RIGHT; CHERRY_MX; Mouser 540-MX1A-11NW
SW57: LEFT; CHERRY_MX; Mouser 540-MX1A-11NW
SW58: DOWN; CHERRY_MX; Mouser 540-MX1A-11NW
SW59: DELETE; CHERRY_MX; Mouser 540-MX1A-11NW
SW60: RT; CHERRY_MX; Mouser 540-MX1A-11NW
U9: CDP1871; DIP254P1524X635-40

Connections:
+5V: C9.1, R2.1, SW3.1, SW4.1, U9.22 (CS2), U9.23 (CS3), U9.40 (VDD); also elsewhere on the board
/BUS0: U9.25 (BUS0); also elsewhere on the board
/BUS1: U9.26 (BUS1); also elsewhere on the board
/BUS2: U9.27 (BUS2); also elsewhere on the board
/BUS3: U9.28 (BUS3); also elsewhere on the board
/BUS4: U9.29 (BUS4); also elsewhere on the board
/BUS5: U9.30 (BUS5); also elsewhere on the board
/BUS6: U9.31 (BUS6); also elsewhere on the board
/BUS7: U9.32 (BUS7); also elsewhere on the board
/TPB: U9.34 (TPB); also elsewhere on the board
/keyboard/~N=3: U9.21 (~CS1); also elsewhere on the board
/~EF3: U9.33 (~DA); also elsewhere on the board
/~KBDRST: SW2.2; also elsewhere on the board
/~MRD: U9.24 (CS4); also elsewhere on the board
/~RTP: U9.35 (~RTP); also elsewhere on the board
GND: C8.2, C9.2, R1.2, R3.2, SW2.4, U9.20 (VSS), U9.37 (ALPHA); also elsewhere on the board
unnamed: C8.1, R2.2, U9.36 (DEBOUNCE)
unnamed: R1.1, SW3.2, U9.39 (SHIFT)
unnamed: R3.1, SW4.2, U9.38 (CONTROL)
unnamed: SW5.1, SW6.1, SW7.1, SW8.1, SW9.1, SW10.1, SW11.1, SW12.1, U9.1 (D1)
unnamed: SW10.2, SW18.2, SW26.2, SW34.2, SW42.2, SW50.2, SW58.2, U9.17 (S6)
unnamed: SW11.2, SW19.2, SW27.2, SW35.2, SW43.2, SW51.2, SW59.2, U9.18 (S7)
unnamed: SW12.2, SW20.2, SW28.2, SW36.2, SW44.2, SW52.2, SW60.2, U9.19 (S8)
unnamed: SW13.1, SW14.1, SW15.1, SW16.1, SW17.1, SW18.1, SW19.1, SW20.1, U9.2 (D2)
unnamed: SW5.2, SW13.2, SW21.2, SW29.2, SW37.2, SW45.2, SW53.2, U9.12 (S1)
unnamed: SW6.2, SW14.2, SW22.2, SW30.2, SW38.2, SW46.2, SW54.2, U9.13 (S2)
unnamed: SW7.2, SW15.2, SW23.2, SW31.2, SW39.2, SW47.2, SW55.2, U9.14 (S3)
unnamed: SW8.2, SW16.2, SW24.2, SW32.2, SW40.2, SW48.2, SW56.2, U9.15 (S4)
unnamed: SW9.2, SW17.2, SW25.2, SW33.2, SW41.2, SW49.2, SW57.2, U9.16 (S5)
unnamed: SW21.1, SW22.1, SW23.1, SW24.1, SW25.1, SW26.1, SW27.1, SW28.1, U9.3 (D3)
unnamed: SW29.1, SW30.1, SW31.1, SW32.1, SW33.1, SW34.1, SW35.1, SW36.1, U9.4 (D4)
unnamed: SW37.1, SW38.1, SW39.1, SW40.1, SW41.1, SW42.1, SW43.1, SW44.1, U9.5 (D5)
unnamed: SW45.1, SW46.1, SW47.1, SW48.1, SW49.1, SW50.1, SW51.1, SW52.1, U9.6 (D6)
unnamed: SW53.1, SW54.1, SW55.1, SW56.1, SW57.1, SW58.1, SW59.1, SW60.1, U9.8 (D8)

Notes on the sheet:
This work is licensed under the Creative Commons Attribution-ShareAlike 4.0 International License. To view a copy of this license, visit http://creativecommons.org/licenses/by-sa/4.0/ or send a letter to Creative Commons, PO Box 1866, Mountain View, CA 94042, USA.
COMIX-35
Keyboard Section By @TubeTimeUS

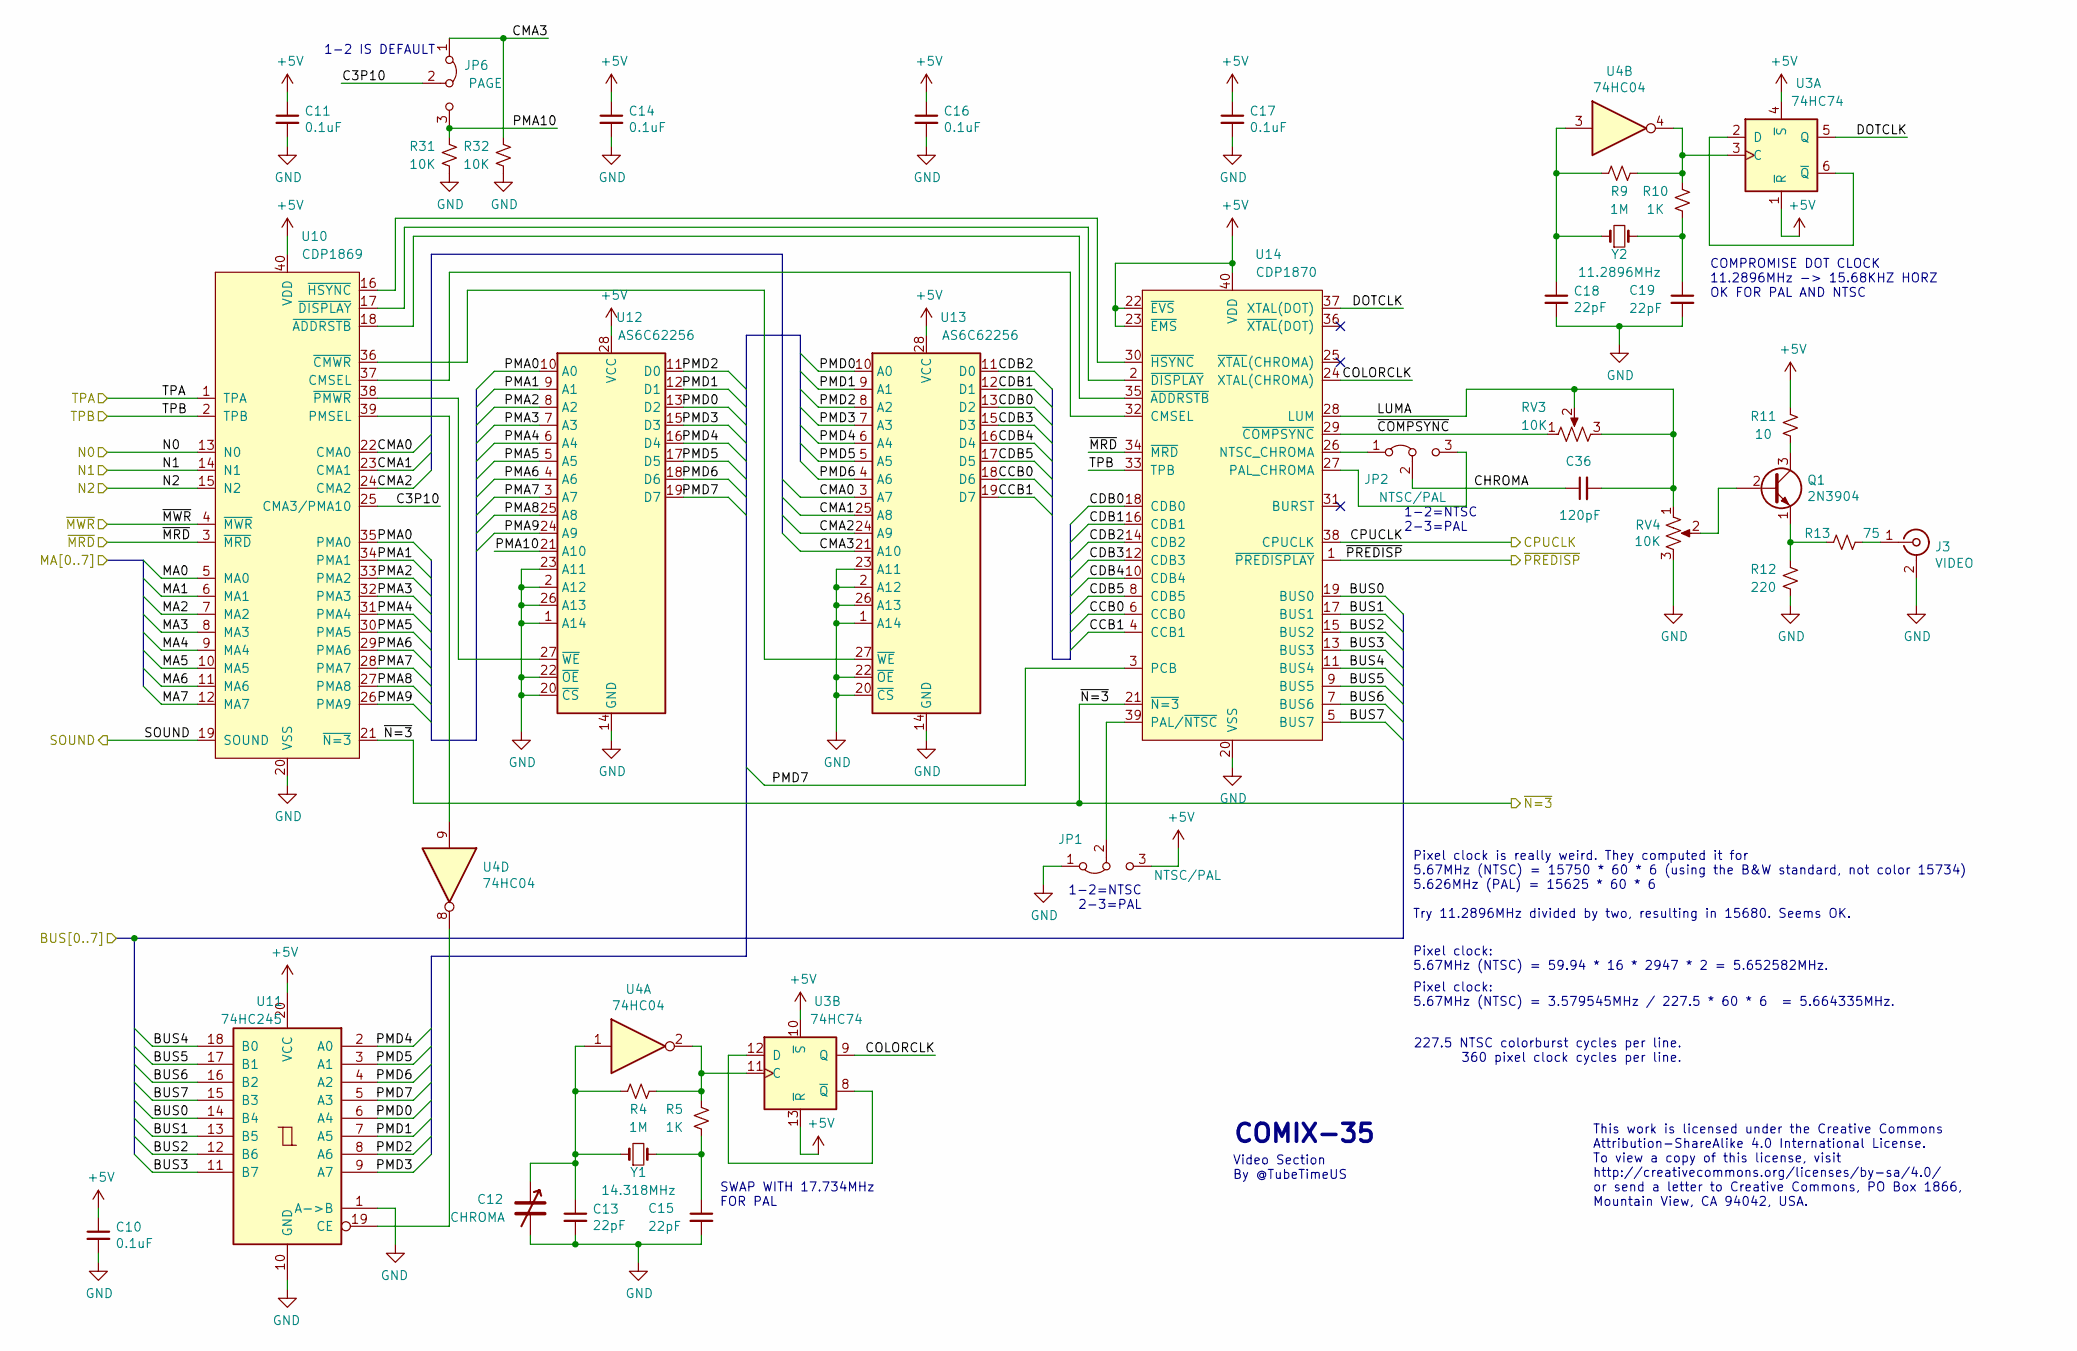
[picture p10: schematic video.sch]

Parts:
C10, C11, C14, C16, C17: 0.1uF; CAPAC200; Mouser 581-SA105E104M
C12: CHROMA; EW_GKG; Digikey 2447-GKG30015-ND
C13, C15, C18, C19: 22pF; CAPAC200; Mouser 810-FG28C0G2A220JNT0
C36: 120pF; CAPAC200; Mouser 810-FG28C0G1H121JNT6
J3: VIDEO; KOBICONN_161-03X0-E; Mouser 161-0360-E
JP1, JP2: NTSC/PAL; Pin_Header_Straight_1x03_Pitch2.54mm
JP6: PAGE; Pin_Header_Straight_1x03_Pitch2.54mm
Q1: 2N3904; TO92-IL; Mouser 512-2N3904BU
R4, R9: 1M; RESA500; Mouser 603-CFR-25JR-521M
R5, R10: 1K; RESA500; Mouser 603-CFR-25JR-521K
R11: 10; RESA500; Mouser 603-CFR-25JR-5210R
R12: 220; RESA500; Mouser 603-CFR-25JR-52220R
R13: 75; RESA500; Mouser 603-CFR-25JR-5275R
R31, R32: 10K; RESA500; Mouser 603-CFR-25JB-52-10K
RV3, RV4: 10K; PIHER_PT10_H01; Mouser 531-PT10H-10K-S
U3: 74HC74; DIP254P762X635-14; Mouser 595-SN74HC74N
U4: 74HC04; DIP254P762X635-14; Mouser 595-SN74HC04N
U10: CDP1869; DIP254P1524X635-40
U11: 74HC245; DIP254P762X635-20; Mouser 595-SN74HC245N
U12, U13: AS6C62256; DIP254P1524X635-28; Mouser 913-AS6C62256-55PCN
U14: CDP1870; DIP254P1524X635-40
Y1: 14.318MHz; Crystal_HC49-4H_Vertical; Mouser 815-ABL-14.31818B2
Y2: 11.2896MHz; Crystal_HC49-4H_Vertical; Mouser 815-ABL-11.2896-B4Y

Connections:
+5V: C10.1, C11.1, C14.1, C16.1, C17.1, JP1.3 (B), R11.1, U3.1 (~R), U3.4 (~S), U3.10 (~S), U3.13 (~R), U10.40 (VDD), U11.20 (VCC), U12.28 (VCC), U13.28 (VCC), U14.22 (~EVS), U14.23 (~EMS), U14.40 (VDD); also elsewhere on the board
/BUS0: U11.14 (B4), U14.19 (BUS0); also elsewhere on the board
/BUS1: U11.13 (B5), U14.17 (BUS1); also elsewhere on the board
/BUS2: U11.12 (B6), U14.15 (BUS2); also elsewhere on the board
/BUS3: U11.11 (B7), U14.13 (BUS3); also elsewhere on the board
/BUS4: U11.18 (B0), U14.11 (BUS4); also elsewhere on the board
/BUS5: U11.17 (B1), U14.9 (BUS5); also elsewhere on the board
/BUS6: U11.16 (B2), U14.7 (BUS6); also elsewhere on the board
/BUS7: U11.15 (B3), U14.5 (BUS7); also elsewhere on the board
/CPUCLK: U14.38 (CPUCLK); also elsewhere on the board
/MA0: U10.5 (MA0); also elsewhere on the board
/MA1: U10.6 (MA1); also elsewhere on the board
/MA2: U10.7 (MA2); also elsewhere on the board
/MA3: U10.8 (MA3); also elsewhere on the board
/MA4: U10.9 (MA4); also elsewhere on the board
/MA5: U10.10 (MA5); also elsewhere on the board
/MA6: U10.11 (MA6); also elsewhere on the board
/MA7: U10.12 (MA7); also elsewhere on the board
/N0: U10.13 (N0); also elsewhere on the board
/N1: U10.14 (N1); also elsewhere on the board
/N2: U10.15 (N2); also elsewhere on the board
/TPA: U10.1 (TPA); also elsewhere on the board
/TPB: U10.2 (TPB), U14.33 (TPB); also elsewhere on the board
/cassetteaudio/SOUND: U10.19 (SOUND); also elsewhere on the board
/keyboard/~N=3: U10.21 (~N=3), U14.21 (~N=3); also elsewhere on the board
/video/C3P10: JP6.2 (C), U10.25 (CMA3/PMA10)
/video/CCB0: U13.18 (D6), U14.6 (CCB0)
/video/CCB1: U13.19 (D7), U14.4 (CCB1)
/video/CDB0: U13.13 (D2), U14.18 (CDB0)
/video/CDB1: U13.12 (D1), U14.16 (CDB1)
/video/CDB2: U13.11 (D0), U14.14 (CDB2)
/video/CDB3: U13.15 (D3), U14.12 (CDB3)
/video/CDB4: U13.16 (D4), U14.10 (CDB4)
/video/CDB5: U13.17 (D5), U14.8 (CDB5)
/video/CHROMA: C36.1, JP2.2 (C)
/video/CMA0: U10.22 (CMA0), U13.3 (A7)
/video/CMA1: U10.23 (CMA1), U13.25 (A8)
/video/CMA2: U10.24 (CMA2), U13.24 (A9)
/video/CMA3: JP6.1 (A), R32.1, U13.21 (A10)
/video/COLORCLK: U3.9 (Q), U14.24 (XTAL(CHROMA))
/video/DOTCLK: U3.5 (Q), U14.37 (XTAL(DOT))
/video/LUMA: C36.2, RV3.2, RV3.3, RV4.1, U14.28 (LUM)
/video/PMA0: U10.35 (PMA0), U12.10 (A0)
/video/PMA1: U10.34 (PMA1), U12.9 (A1)
/video/PMA2: U10.33 (PMA2), U12.8 (A2)
/video/PMA3: U10.32 (PMA3), U12.7 (A3)
/video/PMA4: U10.31 (PMA4), U12.6 (A4)
/video/PMA5: U10.30 (PMA5), U12.5 (A5)
/video/PMA6: U10.29 (PMA6), U12.4 (A6)
/video/PMA7: U10.28 (PMA7), U12.3 (A7)
/video/PMA8: U10.27 (PMA8), U12.25 (A8)
/video/PMA9: U10.26 (PMA9), U12.24 (A9)
/video/PMA10: JP6.3 (B), R31.1, U12.21 (A10)
/video/PMD0: U11.6 (A4), U12.13 (D2), U13.10 (A0)
/video/PMD1: U11.7 (A5), U12.12 (D1), U13.9 (A1)
/video/PMD2: U11.8 (A6), U12.11 (D0), U13.8 (A2)
/video/PMD3: U11.9 (A7), U12.15 (D3), U13.7 (A3)
/video/PMD4: U11.2 (A0), U12.16 (D4), U13.6 (A4)
/video/PMD5: U11.3 (A1), U12.17 (D5), U13.5 (A5)
/video/PMD6: U11.4 (A2), U12.18 (D6), U13.4 (A6)
/video/PMD7: U11.5 (A3), U12.19 (D7), U14.3 (PCB)
/video/~COMPSYNC: RV3.1, U14.29 (~COMPSYNC)
/~MRD: U10.3 (~MRD), U14.34 (~MRD); also elsewhere on the board
/~MWR: U10.4 (~MWR); also elsewhere on the board
/~PREDISP: U14.1 (~PREDISPLAY); also elsewhere on the board
GND: C10.2, C11.2, C12.2, C13.2, C14.2, C15.2, C16.2, C17.2, C18.2, C19.2, J3.2 (Ext), JP1.1 (A), R12.2, R31.2, R32.2, RV4.3, U10.20 (VSS), U11.1 (A->B), U11.10 (GND), U12.1 (A14), U12.2 (A12), U12.14 (GND), U12.20 (~CS), U12.22 (~OE), U12.23 (A11), U12.26 (A13), U13.1 (A14), U13.2 (A12), U13.14 (GND), U13.20 (~CS), U13.22 (~OE), U13.23 (A11), U13.26 (A13), U14.20 (VSS); also elsewhere on the board
unnamed: C12.1, C13.1, R4.1, U4.1, Y1.1
unnamed: C15.1, R5.2, Y1.2
unnamed: C18.1, R9.1, U4.3, Y2.1
unnamed: C19.1, R10.2, Y2.2
unnamed: J3.1 (In), R13.2
unnamed: JP1.2 (C), U14.39 (PAL/~NTSC)
unnamed: JP2.1 (A), U14.26 (NTSC_CHROMA)
unnamed: JP2.3 (B), U14.27 (PAL_CHROMA)
unnamed: Q1.1 (E), R12.1, R13.1
unnamed: Q1.2 (B), RV4.2
unnamed: Q1.3 (C), R11.2
unnamed: R4.2, R5.1, U3.11 (C), U4.2
unnamed: R9.2, R10.1, U3.3 (C), U4.4
unnamed: U3.2 (D), U3.6 (~Q)
unnamed: U3.8 (~Q), U3.12 (D)
unnamed: U10.16 (~HSYNC), U14.30 (~HSYNC)
unnamed: U10.17 (~DISPLAY), U14.2 (~DISPLAY)
unnamed: U10.18 (~ADDRSTB), U14.35 (~ADDRSTB)
unnamed: U10.36 (~CMWR), U13.27 (~WE)
unnamed: U10.37 (CMSEL), U14.32 (CMSEL)
unnamed: U10.38 (~PMWR), U12.27 (~WE)
unnamed: U4.9, U10.39 (PMSEL)
unnamed: U4.8, U11.19 (CE)

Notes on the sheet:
COMPROMISE DOT CLOCK 11.2896MHz -> 15.68KHZ HORZ OK FOR PAL AND NTSC
SWAP WITH 17.734MHz FOR PAL
1-2=NTSC 2-3=PAL
Pixel clock is really weird. They computed it for 5.67MHz (NTSC) = 15750 * 60 * 6 (using the B&W standard, not color 15734) 5.626MHz (PAL) = 15625 * 60 * 6 Try 11.2896MHz divided by two, resulting in 15680. Seems OK.
Pixel clock: 5.67MHz (NTSC) = 59.94 * 16 * 2947 * 2 = 5.652582MHz.
Pixel clock: 5.67MHz (NTSC) = 3.579545MHz / 227.5 * 60 * 6 = 5.664335MHz.
227.5 NTSC colorburst cycles per line. 360 pixel clock cycles per line.
1-2 IS DEFAULT
This work is licensed under the Creative Commons Attribution-ShareAlike 4.0 International License. To view a copy of this license, visit http://creativecommons.org/licenses/by-sa/4.0/ or send a letter to Creative Commons, PO Box 1866, Mountain View, CA 94042, USA.
COMIX-35
Video Section By @TubeTimeUS

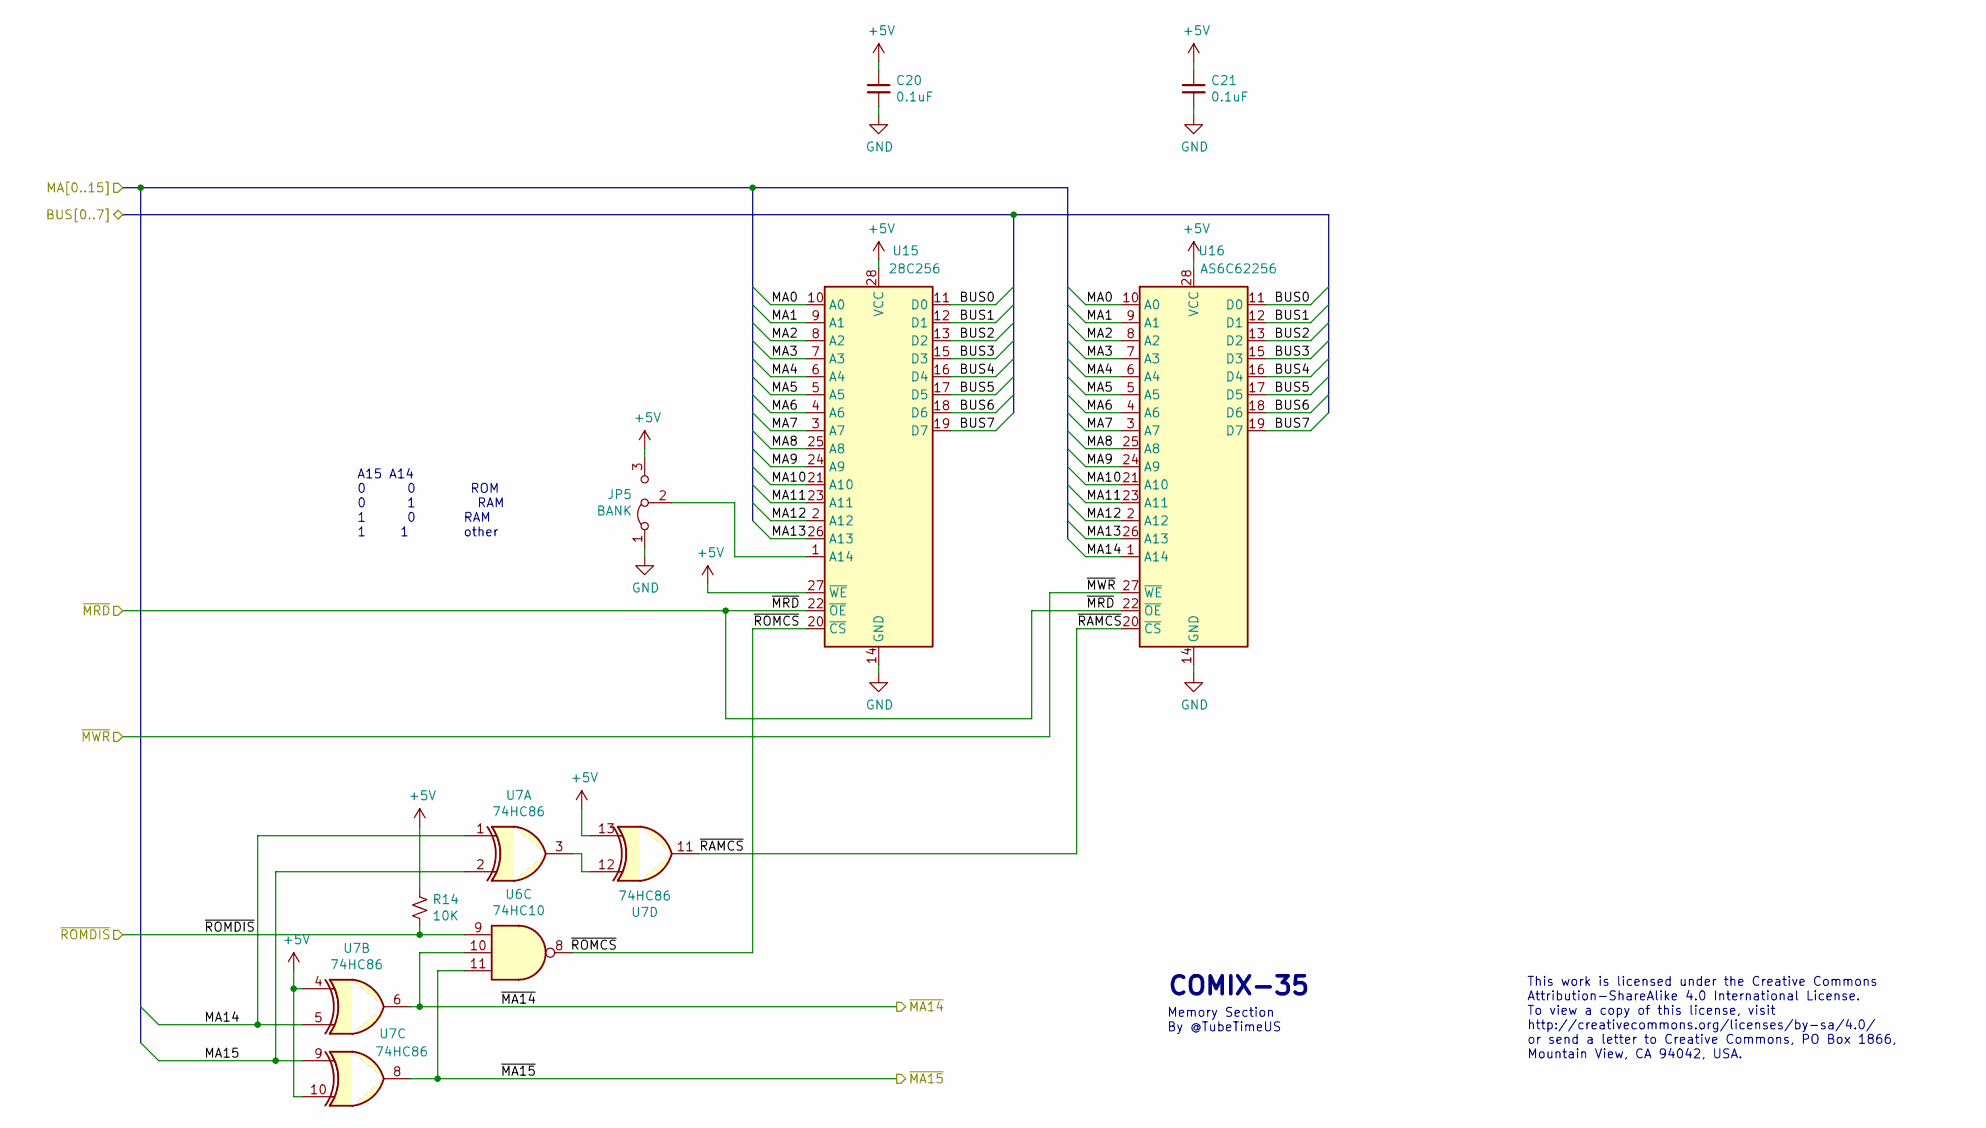
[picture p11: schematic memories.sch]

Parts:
C20, C21: 0.1uF; CAPAC200; Mouser 581-SA105E104M
JP5: BANK; Pin_Header_Straight_1x03_Pitch2.54mm
R14: 10K; RESA500; Mouser 603-CFR-25JB-52-10K
U6: 74HC10; DIP254P762X635-14; Mouser 595-SN74HC10N
U7: 74HC86; DIP254P762X635-14; Mouser 595-SN74HC86N
U15: 28C256; DIP254P1524X635-28; Mouser 556-AT28C25615PU
U16: AS6C62256; DIP254P1524X635-28; Mouser 913-AS6C62256-55PCN

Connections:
+5V: C20.1, C21.1, JP5.3 (B), R14.2, U7.4, U7.10, U7.13, U15.27 (~WE), U15.28 (VCC), U16.28 (VCC); also elsewhere on the board
/BUS0: U15.11 (D0), U16.11 (D0); also elsewhere on the board
/BUS1: U15.12 (D1), U16.12 (D1); also elsewhere on the board
/BUS2: U15.13 (D2), U16.13 (D2); also elsewhere on the board
/BUS3: U15.15 (D3), U16.15 (D3); also elsewhere on the board
/BUS4: U15.16 (D4), U16.16 (D4); also elsewhere on the board
/BUS5: U15.17 (D5), U16.17 (D5); also elsewhere on the board
/BUS6: U15.18 (D6), U16.18 (D6); also elsewhere on the board
/BUS7: U15.19 (D7), U16.19 (D7); also elsewhere on the board
/MA0: U15.10 (A0), U16.10 (A0); also elsewhere on the board
/MA1: U15.9 (A1), U16.9 (A1); also elsewhere on the board
/MA2: U15.8 (A2), U16.8 (A2); also elsewhere on the board
/MA3: U15.7 (A3), U16.7 (A3); also elsewhere on the board
/MA4: U15.6 (A4), U16.6 (A4); also elsewhere on the board
/MA5: U15.5 (A5), U16.5 (A5); also elsewhere on the board
/MA6: U15.4 (A6), U16.4 (A6); also elsewhere on the board
/MA7: U15.3 (A7), U16.3 (A7); also elsewhere on the board
/MA14: U7.1, U7.5, U16.1 (A14); also elsewhere on the board
/cpu/MA8: U15.25 (A8), U16.25 (A8); also elsewhere on the board
/cpu/MA9: U15.24 (A9), U16.24 (A9); also elsewhere on the board
/cpu/MA10: U15.21 (A10), U16.21 (A10); also elsewhere on the board
/cpu/MA11: U15.23 (A11), U16.23 (A11); also elsewhere on the board
/cpu/MA12: U15.2 (A12), U16.2 (A12); also elsewhere on the board
/cpu/MA13: U15.26 (A13), U16.26 (A13); also elsewhere on the board
/cpu/MA15: U7.2, U7.9; also elsewhere on the board
/memories/~RAMCS: U7.11, U16.20 (~CS)
/memories/~ROMCS: U6.8, U15.20 (~CS)
/~MA14: U6.10, U7.6; also elsewhere on the board
/~MA15: U6.11, U7.8; also elsewhere on the board
/~MRD: U15.22 (~OE), U16.22 (~OE); also elsewhere on the board
/~MWR: U16.27 (~WE); also elsewhere on the board
/~ROMDIS: R14.1, U6.9; also elsewhere on the board
GND: C20.2, C21.2, JP5.1 (A), U15.14 (GND), U16.14 (GND); also elsewhere on the board
unnamed: JP5.2 (C), U15.1 (A14)
unnamed: U7.3, U7.12

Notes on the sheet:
A15 A14 0 0 ROM 0 1 RAM 1 0 RAM 1 1 other
This work is licensed under the Creative Commons Attribution-ShareAlike 4.0 International License. To view a copy of this license, visit http://creativecommons.org/licenses/by-sa/4.0/ or send a letter to Creative Commons, PO Box 1866, Mountain View, CA 94042, USA.
COMIX-35
Memory Section By @TubeTimeUS

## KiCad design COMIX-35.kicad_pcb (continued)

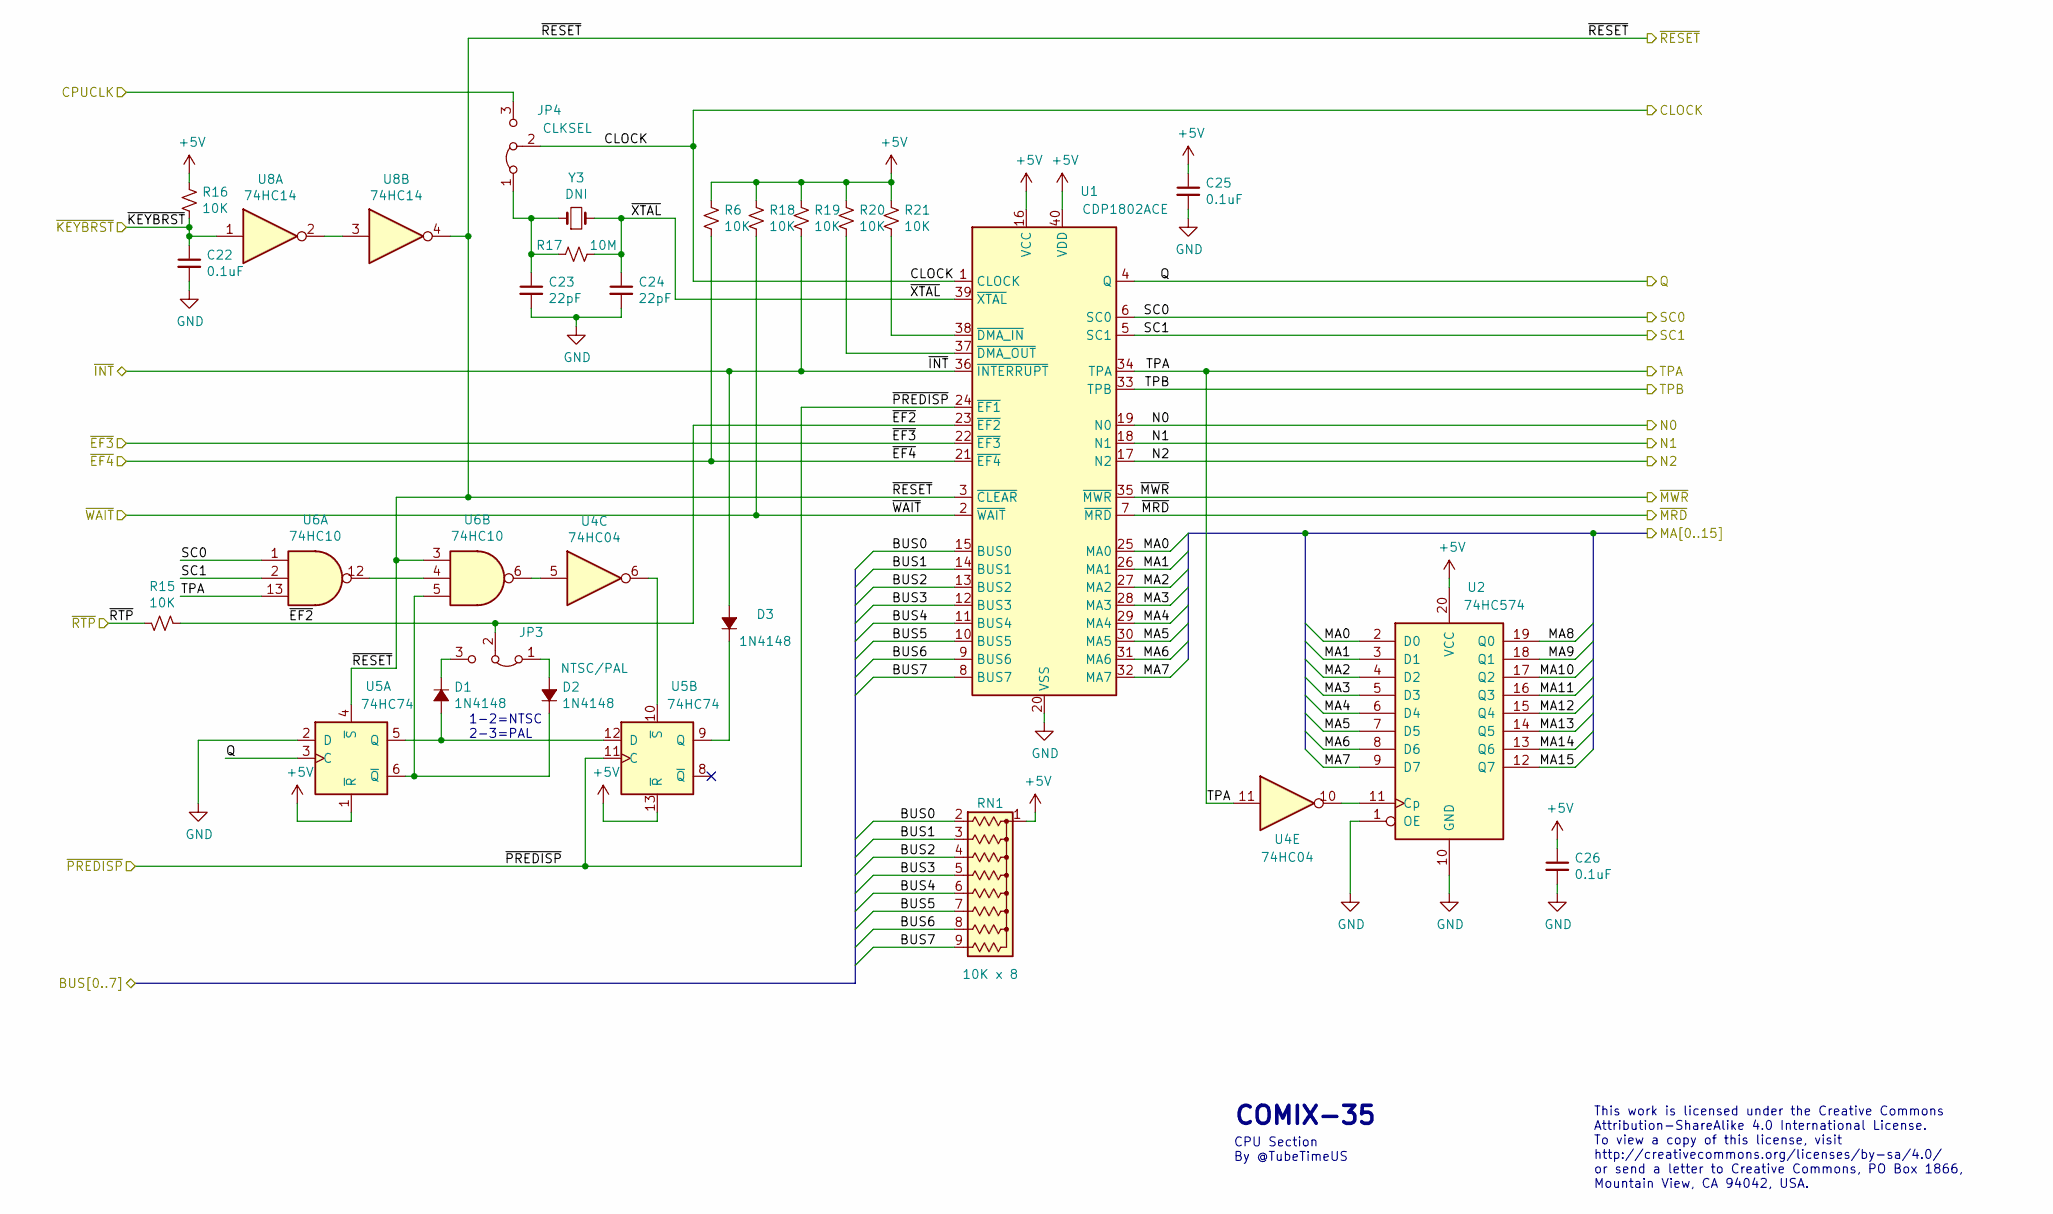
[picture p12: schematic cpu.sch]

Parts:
C22, C25, C26: 0.1uF; CAPAC200; Mouser 581-SA105E104M
C23, C24: 22pF; CAPAC200; Mouser 810-FG28C0G2A220JNT0
D1, D2, D3: 1N4148; DIOA500; Mouser 512-1N4148
JP3: NTSC/PAL; Pin_Header_Straight_1x03_Pitch2.54mm
JP4: CLKSEL; Pin_Header_Straight_1x03_Pitch2.54mm
R6, R15, R16, R18, R19, R20, R21: 10K; RESA500; Mouser 603-CFR-25JB-52-10K
R17: 10M; RESA500; Mouser 603-CFR-25JT-52-10M
RN1: 10K x 8; Pin_Header_Straight_1x09_Pitch2.54mm; Mouser 652-4609X-1LF-10K
U1: CDP1802ACE; DIP254P1524X635-40
U2: 74HC574; DIP254P762X635-20; Mouser 595-SN74HC574N
U4: 74HC04; DIP254P762X635-14; Mouser 595-SN74HC04N
U5: 74HC74; DIP254P762X635-14; Mouser 595-SN74HC74N
U6: 74HC10; DIP254P762X635-14; Mouser 595-SN74HC10N
U8: 74HC14; DIP254P762X635-14; Mouser 595-SN74HC14N
Y3: DNI; Crystal_HC49-4H_Vertical; Mouser DNI

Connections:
+5V: C25.1, C26.1, R6.2, R16.2, R18.2, R19.2, R20.2, R21.2, RN1.1 (common), U1.16 (VCC), U1.40 (VDD), U2.20 (VCC), U5.1 (~R), U5.13 (~R); also elsewhere on the board
/BUS0: RN1.2 (R1), U1.15 (BUS0); also elsewhere on the board
/BUS1: RN1.3 (R2), U1.14 (BUS1); also elsewhere on the board
/BUS2: RN1.4 (R3), U1.13 (BUS2); also elsewhere on the board
/BUS3: RN1.5 (R4), U1.12 (BUS3); also elsewhere on the board
/BUS4: RN1.6 (R5), U1.11 (BUS4); also elsewhere on the board
/BUS5: RN1.7 (R6), U1.10 (BUS5); also elsewhere on the board
/BUS6: RN1.8 (R7), U1.9 (BUS6); also elsewhere on the board
/BUS7: RN1.9 (R8), U1.8 (BUS7); also elsewhere on the board
/CLOCK: JP4.2 (C), U1.1 (CLOCK); also elsewhere on the board
/CPUCLK: JP4.3 (B); also elsewhere on the board
/MA0: U1.25 (MA0), U2.2 (D0); also elsewhere on the board
/MA1: U1.26 (MA1), U2.3 (D1); also elsewhere on the board
/MA2: U1.27 (MA2), U2.4 (D2); also elsewhere on the board
/MA3: U1.28 (MA3), U2.5 (D3); also elsewhere on the board
/MA4: U1.29 (MA4), U2.6 (D4); also elsewhere on the board
/MA5: U1.30 (MA5), U2.7 (D5); also elsewhere on the board
/MA6: U1.31 (MA6), U2.8 (D6); also elsewhere on the board
/MA7: U1.32 (MA7), U2.9 (D7); also elsewhere on the board
/MA14: U2.13 (Q6); also elsewhere on the board
/N0: U1.19 (N0); also elsewhere on the board
/N1: U1.18 (N1); also elsewhere on the board
/N2: U1.17 (N2); also elsewhere on the board
/Q: U1.4 (Q), U5.3 (C); also elsewhere on the board
/SC0: U1.6 (SC0), U6.1; also elsewhere on the board
/SC1: U1.5 (SC1), U6.2; also elsewhere on the board
/TPA: U1.34 (TPA), U4.11, U6.13; also elsewhere on the board
/TPB: U1.33 (TPB); also elsewhere on the board
/cpu/MA8: U2.19 (Q0); also elsewhere on the board
/cpu/MA9: U2.18 (Q1); also elsewhere on the board
/cpu/MA10: U2.17 (Q2); also elsewhere on the board
/cpu/MA11: U2.16 (Q3); also elsewhere on the board
/cpu/MA12: U2.15 (Q4); also elsewhere on the board
/cpu/MA13: U2.14 (Q5); also elsewhere on the board
/cpu/MA15: U2.12 (Q7); also elsewhere on the board
/cpu/~EF2: JP3.2 (C), R15.2, U1.23 (~EF2)
/cpu/~XTAL: C24.1, R17.2, U1.39 (~XTAL), Y3.2
/~EF3: U1.22 (~EF3); also elsewhere on the board
/~EF4: R6.1, U1.21 (~EF4); also elsewhere on the board
/~INT: D3.2 (A), R19.1, U1.36 (~INTERRUPT); also elsewhere on the board
/~KBDRST: C22.1, R16.1, U8.1; also elsewhere on the board
/~MRD: U1.7 (~MRD); also elsewhere on the board
/~MWR: U1.35 (~MWR); also elsewhere on the board
/~PREDISP: U1.24 (~EF1), U5.11 (C); also elsewhere on the board
/~RESET: U1.3 (~CLEAR), U5.4 (~S), U6.3, U8.4; also elsewhere on the board
/~RTP: R15.1; also elsewhere on the board
/~WAIT: R18.1, U1.2 (~WAIT); also elsewhere on the board
GND: C22.2, C23.2, C24.2, C25.2, C26.2, U1.20 (VSS), U2.1 (OE), U2.10 (GND), U5.2 (D); also elsewhere on the board
unnamed: C23.1, JP4.1 (A), R17.1, Y3.1
unnamed: D1.1 (K), JP3.3 (B)
unnamed: D1.2 (A), U5.5 (Q), U5.12 (D)
unnamed: D2.1 (K), U5.6 (~Q), U6.5
unnamed: D2.2 (A), JP3.1 (A)
unnamed: D3.1 (K), U5.9 (Q)
unnamed: R20.1, U1.37 (~DMA_OUT)
unnamed: R21.1, U1.38 (~DMA_IN)
unnamed: U2.11 (Cp), U4.10
unnamed: U4.5, U6.6
unnamed: U4.6, U5.10 (~S)
unnamed: U6.4, U6.12
unnamed: U8.2, U8.3

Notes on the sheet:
1-2=NTSC 2-3=PAL
This work is licensed under the Creative Commons Attribution-ShareAlike 4.0 International License. To view a copy of this license, visit http://creativecommons.org/licenses/by-sa/4.0/ or send a letter to Creative Commons, PO Box 1866, Mountain View, CA 94042, USA.
COMIX-35
CPU Section By @TubeTimeUS

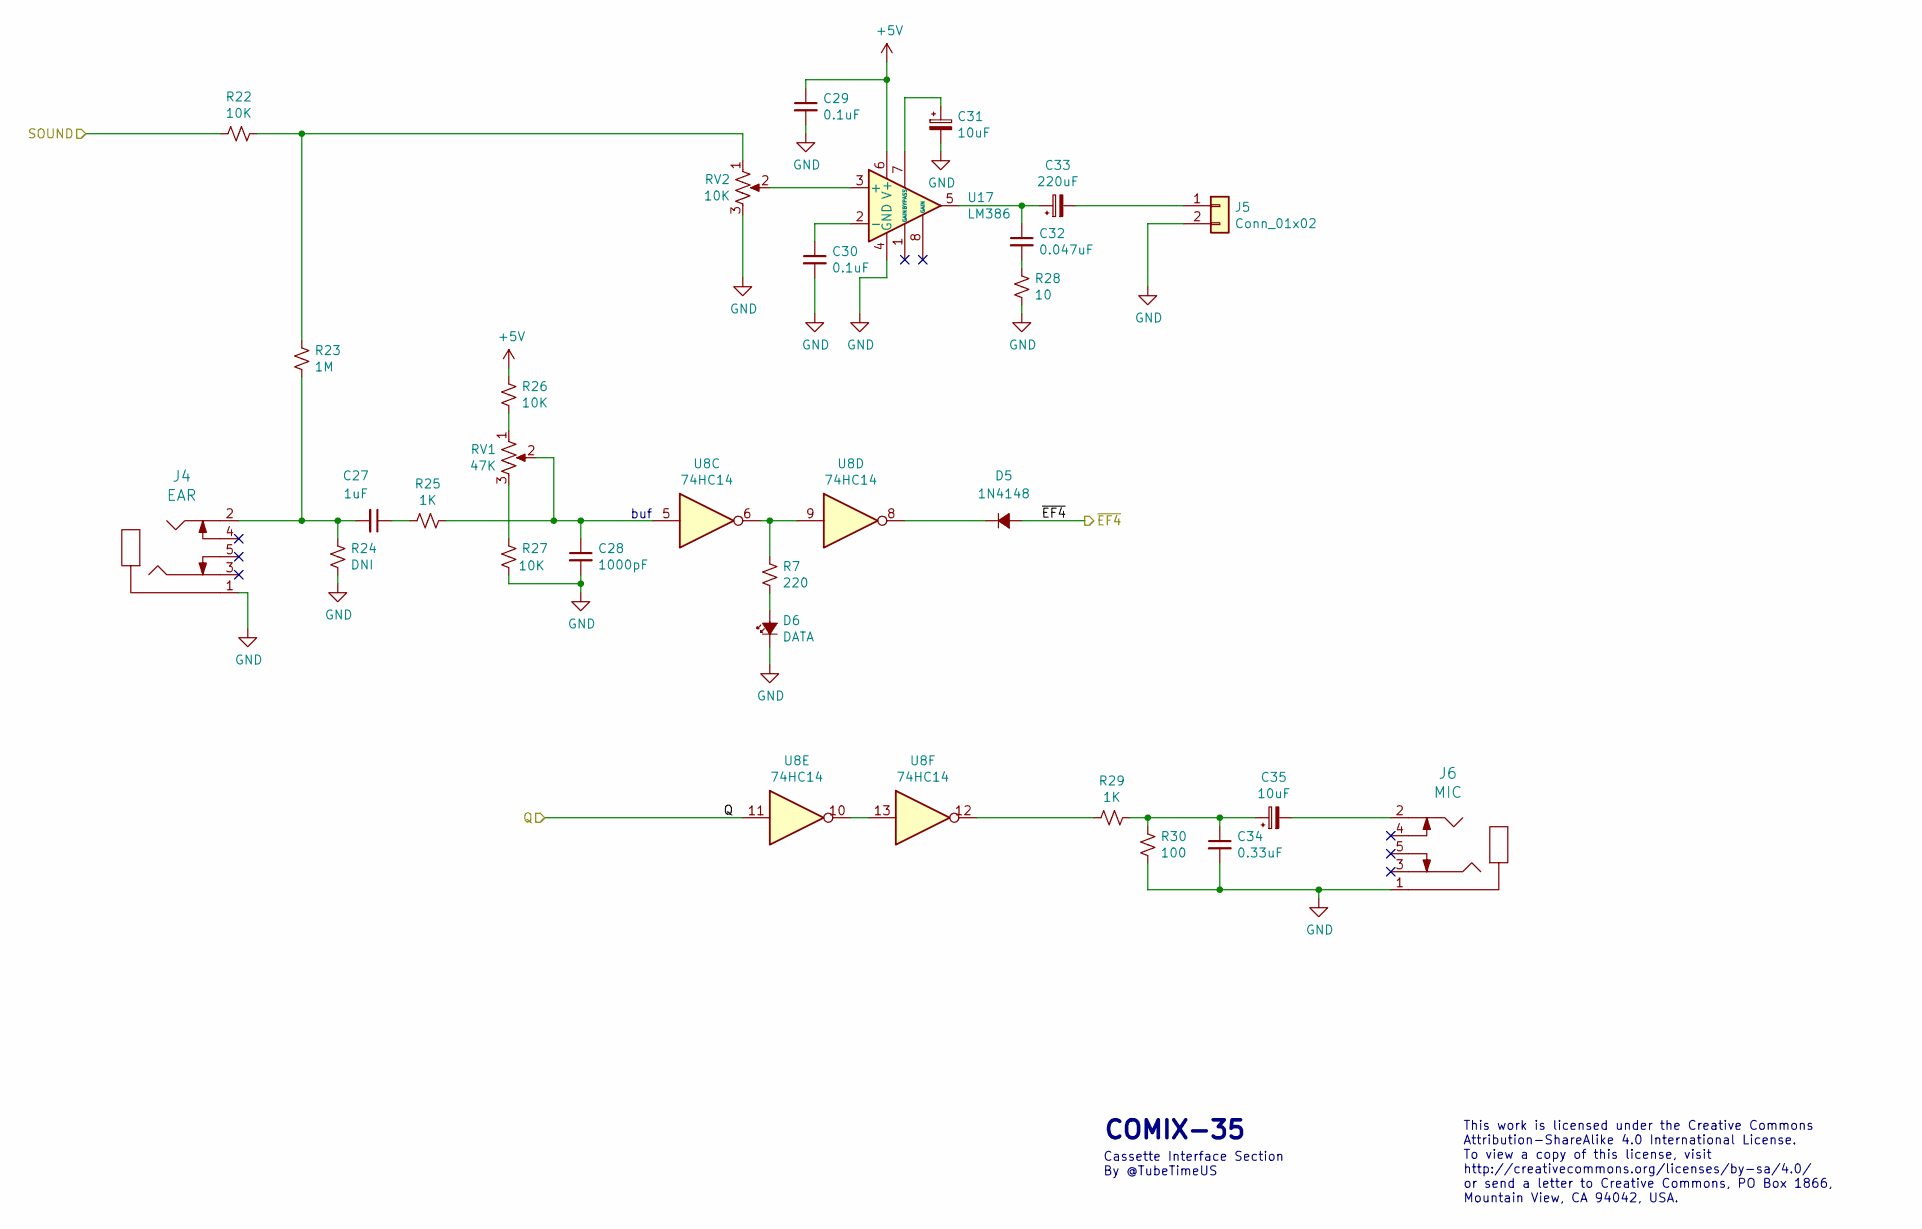
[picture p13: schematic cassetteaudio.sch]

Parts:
C27: 1uF; CAPAC200; Mouser 810-FG24X7R1H334KNT6
C28: 1000pF; CAPAC200; Mouser 810-FG28X7R1H102KNT6
C29, C30: 0.1uF; CAPAC200; Mouser 581-SA105E104M
C31, C35: 10uF; CAPAE250P630X1100; Mouser 667-ECA-1CM100I
C32: 0.047uF; CAPAC200; Mouser 810-FA28X7R1H47300
C33: 220uF; CAPAE250P630X1100; Mouser 647-UVY1E221MED1TD
C34: 0.33uF; CAPAC200; Mouser 810-FG28X7R1H334KRT0
D5: 1N4148; DIOA500; Mouser 512-1N4148
D6: DATA; LED_D5.0mm; Mouser 859-LTL-4213
J4: EAR; CUI_SJ1-353XN; Mouser 490-SJ1-3533NG
J5: Conn_01x02; Pin_Header_Straight_1x02_Pitch2.54mm
J6: MIC; CUI_SJ1-353XN; Mouser 490-SJ1-3533NG
R7: 220; RESA500; Mouser 603-CFR-25JR-52220R
R22, R26, R27: 10K; RESA500; Mouser 603-CFR-25JB-52-10K
R23: 1M; RESA500; Mouser 603-CFR-25JR-521M
R24: DNI; RESA500; Mouser DNI
R25, R29: 1K; RESA500; Mouser 603-CFR-25JR-521K
R28: 10; RESA500; Mouser 603-CFR-25JR-5210R
R30: 100; RESA500; Mouser 603-CFR-25JR-52100R
RV1: 47K; PIHER_PT10_H01; Mouser 531-PT10LH01473A22S
RV2: 10K; PIHER_PT10_H01; Mouser 531-PT10H-10K-S
U8: 74HC14; DIP254P762X635-14; Mouser 595-SN74HC14N
U17: LM386; DIP254P762X635-8; Mouser 926-LM386N-4/NOPB

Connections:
+5V: C29.1, R26.1, U17.6 (V+); also elsewhere on the board
/Q: U8.11; also elsewhere on the board
/cassetteaudio/SOUND: R22.2; also elsewhere on the board
/~EF4: D5.2 (A); also elsewhere on the board
GND: C28.2, C29.2, C30.2, C31.2, C34.2, D6.1 (K), J4.1, J5.2, J6.1, R24.1, R27.2, R28.2, R30.2, RV2.3, U17.4 (GND); also elsewhere on the board
unnamed: C27.1, R25.2
unnamed: C27.2, J4.2, R23.2, R24.2
unnamed: C28.1, R25.1, RV1.2, U8.5
unnamed: C30.1, U17.2 (-)
unnamed: C31.1, U17.7 (BYPASS)
unnamed: C32.1, C33.1, U17.5
unnamed: C32.2, R28.1
unnamed: C33.2, J5.1
unnamed: C34.1, C35.1, R29.1, R30.1
unnamed: C35.2, J6.2
unnamed: D5.1 (K), U8.8
unnamed: D6.2 (A), R7.1
unnamed: R7.2, U8.6, U8.9
unnamed: R22.1, R23.1, RV2.1
unnamed: R26.2, RV1.1
unnamed: R27.1, RV1.3
unnamed: R29.2, U8.12
unnamed: RV2.2, U17.3 (+)
unnamed: U8.10, U8.13

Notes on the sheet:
buf
This work is licensed under the Creative Commons Attribution-ShareAlike 4.0 International License. To view a copy of this license, visit http://creativecommons.org/licenses/by-sa/4.0/ or send a letter to Creative Commons, PO Box 1866, Mountain View, CA 94042, USA.
COMIX-35
Cassette Interface Section By @TubeTimeUS

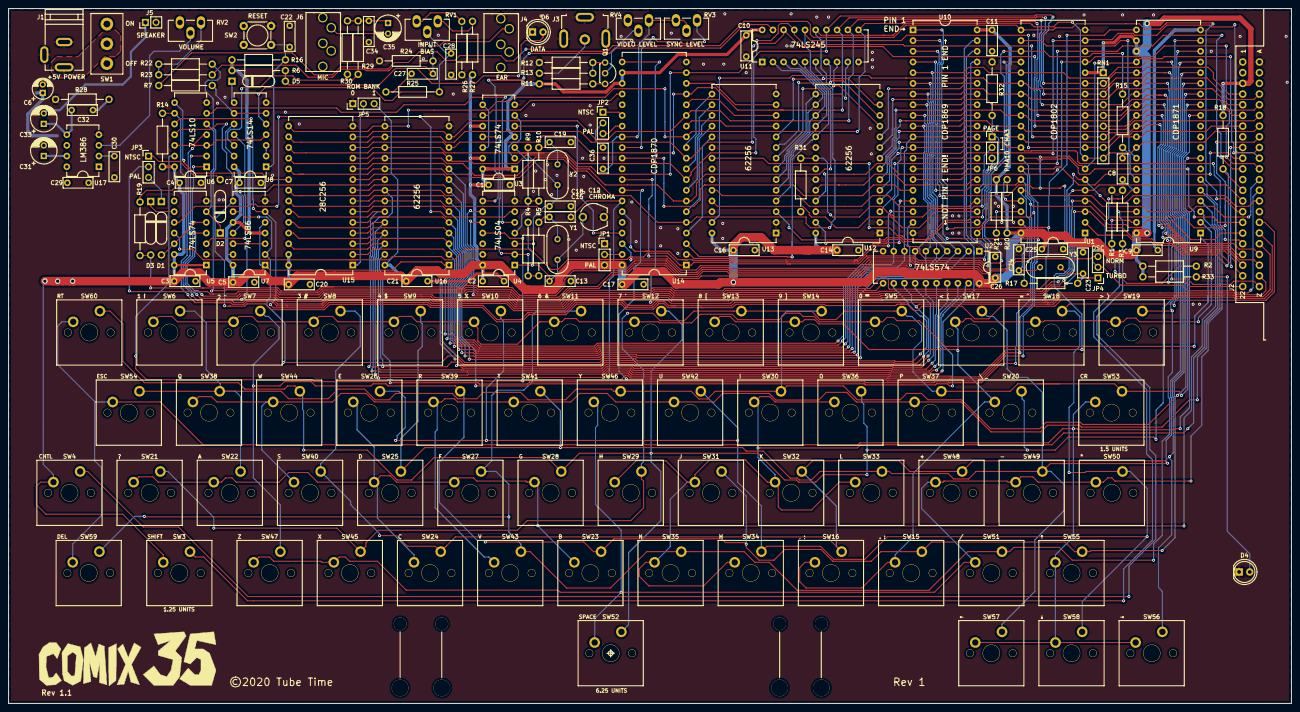
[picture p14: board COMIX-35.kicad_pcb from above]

Board: 2 copper layers, 304.8 x 165.1 mm, 173 parts (0 on the bottom side), 169 nets.

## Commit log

2020-07-26 Initial commit.
    [COMIX-35.csv, COMIX-35.kicad_pcb, COMIX-35.sch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]
2020-08-06 U4 is now 74HCU04. Added comments in readme.
    [COMIX-35.csv, COMIX-35.sch]

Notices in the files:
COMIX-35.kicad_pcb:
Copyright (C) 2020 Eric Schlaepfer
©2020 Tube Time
